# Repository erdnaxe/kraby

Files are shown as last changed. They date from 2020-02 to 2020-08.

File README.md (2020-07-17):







# Kraby

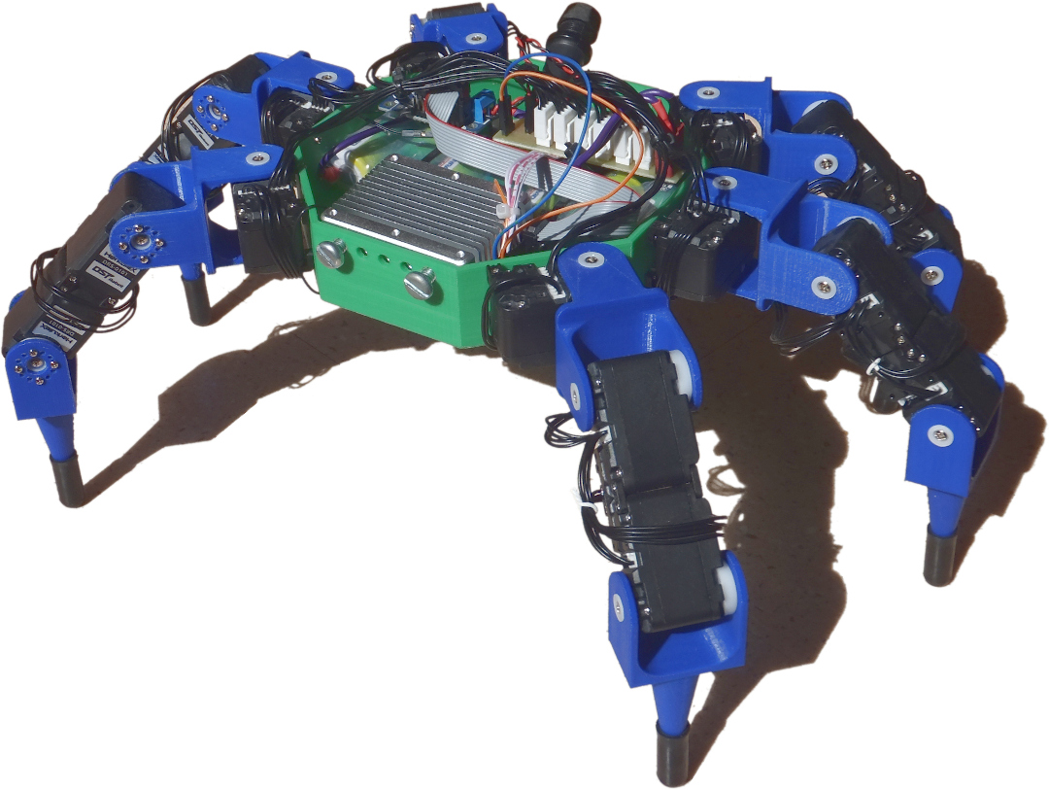
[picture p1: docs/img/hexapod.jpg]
Hexapod robot


Kraby is an hexapod robot.
It is an open source development platform for educational purpose.
It was designed for a Master 1
project at [ENS Paris-Saclay](https://ens-paris-saclay.fr/).

You may read documentation at <https://kraby.readthedocs.io/>

## Build the documentation

Install `mkdocs` then run `mkdocs serve`.

## Install OpenAI environment

```bash
pip install gym_kraby --user
python -m gym_kraby.demo
```

To test servomotors communication with the robot, you may execute `python -m gym_kraby.utils.herkulex_socket`.

## License

This project is under MIT License because we believe in
open development. Please see LICENSE file for more details.

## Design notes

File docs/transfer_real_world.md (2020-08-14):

**Table of content**:

[TOC]

* * *

# Preparing transfer to real world

The different learning experiments done last section were done with a environment time step of 50 ms,
which is the minimum period at which we can control and observe all servomotors.

As explained in [observation vector comparisons](training_one_leg.md#observation-vector-comparison),
**all the simulation observation is observable in the real world.**
No need to implement the direct mechanics to compute the position of the fingertip.

Each environment got it "real world" equivalent, that will not use PyBullet and will **not be able to compute a reward**.

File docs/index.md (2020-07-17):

# Kraby

Open-source hexapod robot.

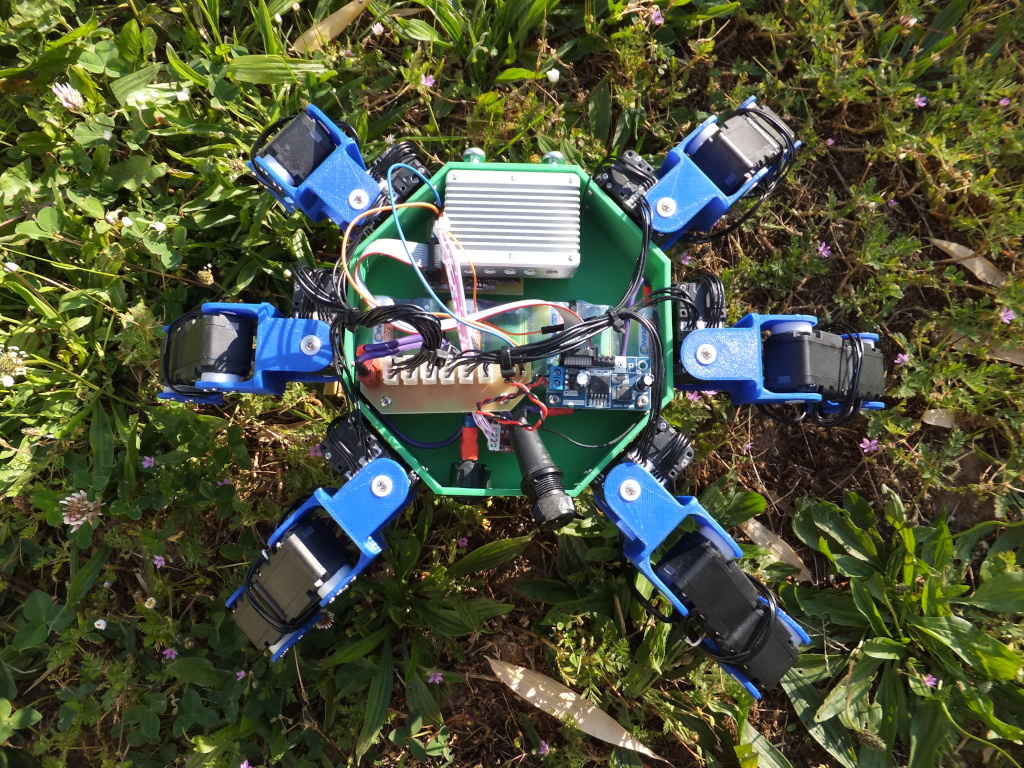
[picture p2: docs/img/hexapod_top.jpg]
Hexapod robot top view


* * *

## Overview

Kraby is an **open-source**, **3d-printable** hexapod robot that is geared towards
building a solid development platform for research and educational purpose.

The robot was designed during a Master 1
project at [ENS Paris-Saclay](https://ens-paris-saclay.fr/), France.

### Easy to remix

The robot was designed using [Blender](https://www.blender.org/),
a free and open-source 3D computer graphics editing software.
Download and remix [Kraby Blender sources](https://github.com/erdnaxe/kraby/tree/master/3d_parts/Blender).

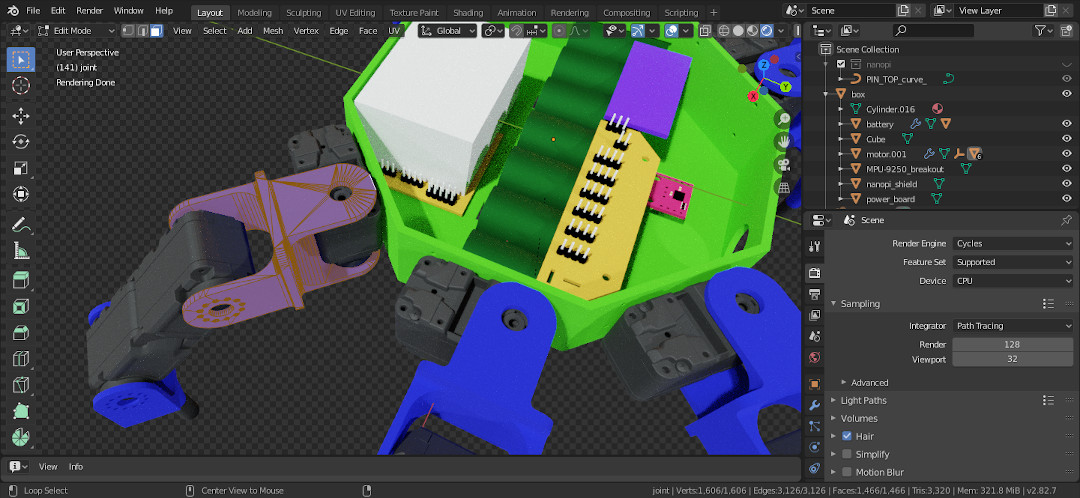
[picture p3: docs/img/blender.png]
Blender in mesh edit mode


### Smart servo-motors

Kraby uses 18 **Herkulex DRS-0101** servomotors from Dongbu to stay cost
effective while offering reasonable performances.
These includes a DC motor, a gear reducer, a control circuitry and
serial communications capability.
These servomotors are able to measure motor torque and speed, and are easy to
use with a serial port.

Even though the embedded computer has two free serial ports, getting all sensors values of 18 servomotors take an average of 40 ms, see [more details there](use_motors.md#how-slow-is-it).
This means Kraby may be too slow to do proper torque control, that is why we try to use them in position control.

These servomotors are similar to the more popular **Dynamixel AX-12**.

### Simulation environment included

[OpenAI Gym](https://gym.openai.com/) environments are available and packaged as [gym-kraby](https://pypi.org/project/gym-kraby/) on PyPi.
It uses [BulletPhysics](https://github.com/bulletphysics/bullet3) simulator
with [an URDF description](https://github.com/erdnaxe/kraby/blob/master/gym_kraby/data/hexapod.urdf) of the robot,
see [more details there](gym_environments.md).

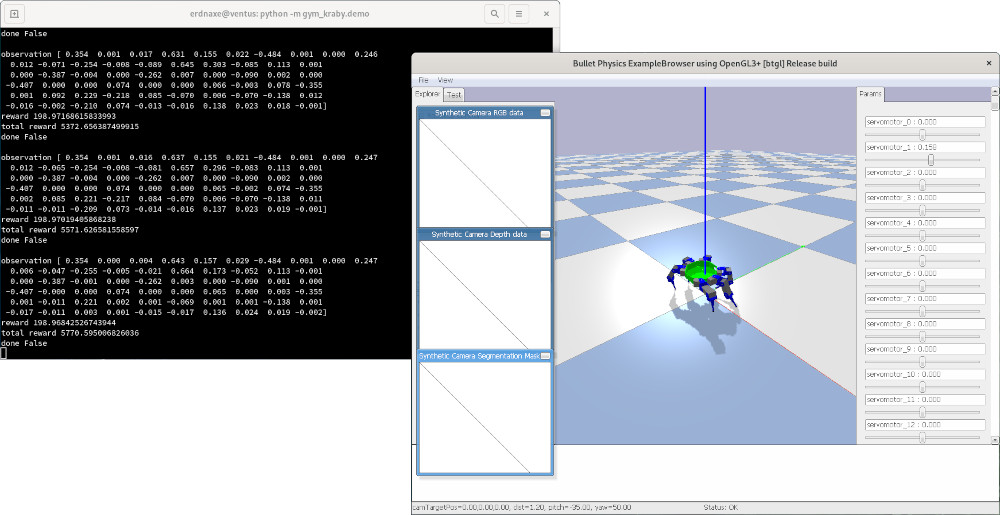
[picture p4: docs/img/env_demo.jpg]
OpenAI Gym environment


* * *

## Build instructions

To build a fully featured robot you will need to
[build the structure](build_the_structure)
then [build the electronics](build_the_electronics).

* * *

## Getting help

To get help with Kraby,
please join [#kraby:auro.re](https://matrix.to/#/#kraby:auro.re) Matrix room or
use [GitHub issues](https://github.com/erdnaxe/kraby/issues).

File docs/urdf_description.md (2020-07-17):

**Table of content**:

[TOC]

* * *

# URDF description

The **Unified Robot Description Format** (URDF) is an XML format
for representing a robot model. It has been developed
by the Robotic Operating System project (ROS).

Kraby URDF description is available at
<https://github.com/erdnaxe/kraby/blob/master/gym_kraby/data/hexapod.urdf>.

!!! Note "Do not use SDF"

    This project started with a SDFormat description of the robot in Gazebo.
    Despite PyBullet being able to load SDF files, the support is not as good as URDF files
    and some simulation parameters were impossible to input.

## Editing and building the URDF with Jinja templating

To simplify URDF editing and to avoid input errors,
the project uses Jinja2[^xacro] templates to generate the URDF.
You may edit files under
[gym_kraby/data/src/](https://github.com/erdnaxe/kraby/tree/master/gym_kraby/data/src)
then execute
[gym_kraby/data/generate_urdf.py](https://github.com/erdnaxe/kraby/tree/master/gym_kraby/data).

## Computing 3d-printed part inertia

[Meshlab](http://www.meshlab.net/) is able to compute a inertia tensor from
a STL file with the "_Compute Geometric Measures_" filter.
Nevertheless the STL is in millimeter and Meshlab implies a density of 1.
The following Python script is able to take MeshLab output and print the
corresponding inertia URDF tag.

```Python
mass = float(input("Object Mass is : "))
volume = float(input("Mesh Volume is : "))
print("Inertia Tensor is :")
j = [list(map(float, input("  ").strip().split(" "))) for _ in range(3)]

for i in range(3):
    for k in range(3):
        # Change density and convert millimeter to meter
        j[i][k] *= mass/volume*0.000001

print(f"""\n<inertia ixx="{j[0][0]:.16f}" ixy="{j[0][1]:.16f}" ixz="{j[0][2]:.16f}" iyy="{j[1][1]:.16f}" iyz="{j[1][2]:.16f}" izz="{j[2][2]:.16f}" />""")
```

For example, this is the input and output to computer a foot inertia.

```bash
% python3 compute_inertia.py
Object Mass is : 0.0105
Mesh Volume is : 15253.618164
Inertia Tensor is :
  8171479.500000 -1091.582153 858.932007
  -1091.582153 6636559.000000 29447.435547
  858.932007 29447.435547 2481984.750000    

<inertia ixx="0.0000056249300217" ixy="-0.0000000007514029"
          ixz="0.0000000005912555" iyy="0.0000045683501941"
          iyz="0.0000000202704742" izz="0.0000017085021793" />
```

For more information, see
<http://gazebosim.org/tutorials?tut=inertia&cat=build_robot>.

[^xacro]: [Xacro](http://wiki.ros.org/xacro) could also be an option, but it requires to install the ROS toolchain.

# PyBullet integration

Now that our robot is fully described in URDF, we may load it in BulletPhysics using PyBullet Python bindings.

```Python
import pybullet as p

p.connect(p.GUI)  # Open new physic server with GUI
p.setGravity(0, 0, -9.81)  # No, we are still on earth
p.setAdditionalSearchPath(getDataPath())  # Add pybullet_data
p.loadURDF("plane.urdf")  # Load a ground
p.loadURDF("hexapod.urdf")  # Load the full robot
```

You may then use `p.setJointMotorControlArray` to control motors.

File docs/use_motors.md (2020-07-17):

**Table of content**:

[TOC]

* * *

# Send and receive data from servomotors

The NanoPi NEO4 has five 3.3V UART that can go up to 1.5 Mbauds/s.
Two of these UART are used by the gigabit Ethernet controler
and one is used by the Bluetooth[^nanopi_wiki].

The [printed circuit boards](build_the_electronics.md) connect all
Herkulex DRS-0101 on NanoPi serial port `/dev/ttyS4` (UART4, 40-pin, GPIO1).
The debug UART (UART2, 8-pin, GPIO3) is unused.

## Initial set-up

To make everything go smoothly, you need to set each servomotors identifier
and make sure they are communicating at 500 000 bauds/s.
This can be done manually by connecting one servomotor at a time.
You may want to use a software like
[Herkulex Manager](http://hovis.co.kr/guide/herkulex_manager_eng.html)
to ease this process.

This indexing is the same in the URDF
and offers an easier way
to transfer a simulated control agent to the real robot.

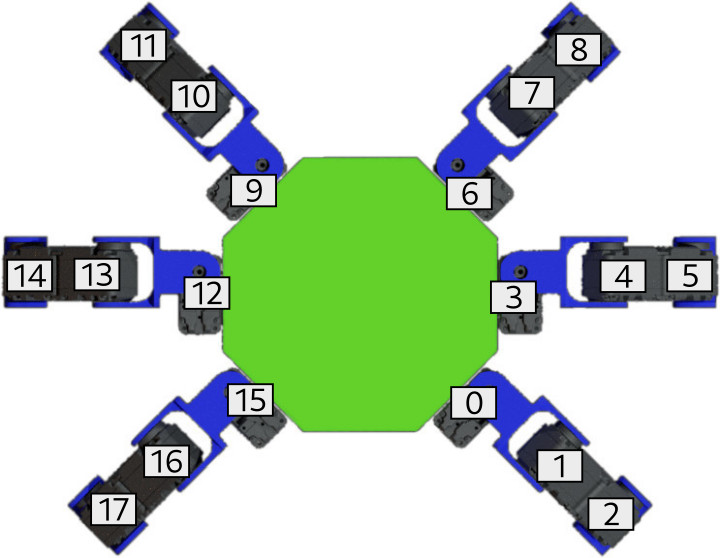
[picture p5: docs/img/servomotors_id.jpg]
servomotors id


!!! warning "Max baud-rate"

    Herkulex DRS-0101 are able to communicate in series as fast as 0.667 Mbauds/s.
    Nevertheless **RK3399 boards are unable to communicate at that baud-rate
    as their base baud-rate is 1.5 Mbaud/s[^rk3399dtsi]**.
    So 0.5 Mbaud/s is a good compromise (divided by 3 rather than 2.25).

## Server-side

### With ser2net

To ease development, `ser2net` can be used to publish
this serial port to a TCP socket.
Then, this TCP socket can be used one the same network, on a computer connected to the robot or locally.

```bash
sudo apt install ser2net
sudo systemctl enable ser2net
```

Then edit `/etc/ser2net.conf` and replace the last lines with

```ini
2000:raw:600:/dev/ttyS4:500000 8DATABITS NONE 1STOPBIT
```

This will publish `/dev/ttyS4` with a baud-rate of 500 000 baud/s,
and some common serial configuration to `0.0.0.0:2000`.

Now, you may restart the service with `sudo systemctl restart ser2net`.

!!! note

    If you improperly disconnect the socket too many times,
    then you may need to restart `ser2net` service to clean up dead sockets.

### With socat

It is possible to achieve the same result with a `socat` relay.

```bash
socat tcp-listen:2000,reuseaddr,fork file:/dev/ttyS4,raw,nonblock,waitlock=/tmp/s0.lock,echo=0,b500000
```

`tcp-listen:2000` makes socat listen on TCP 2000.
The serial TTY is open as `raw` to pass input and output unprocessed,
`nonblock` to open in nonblocking mode,
`echo=0` to disable local echo,
`b500000` to set the baud-rate.

You may also consider using UDP to achieve faster commands,

```bash
socat udp-recvfrom:2000,fork file:/dev/ttyS4,raw,nonblock,echo=0,b500000
```

You may have to write a Systemd service unit to establish these relays at boot,
edit `/etc/systemd/system/socat-tcp.service`:

```ini
[Unit]
Description=Socat TCP to ttyS4 relay
After=network-online.target

[Service]
Type=simple
ExecStart=/usr/bin/socat tcp-listen:2000,reuseaddr,fork file:/dev/ttyS4,raw,nonblock,waitlock=/tmp/s0.lock,echo=0,b500000
Restart=on-failure

[Install]
WantedBy=multi-user.target
```

## Client-side

A client implementation is available at
<https://github.com/erdnaxe/kraby/blob/master/gym_kraby/utils/herkulex_socket.py>.

This client is able to control the robot and get positions,
velocities and speeds from all servomotors.

You can send a demo choreography to `10.42.0.1:2000` with:

```bash
python -m gym_kraby.utils.herkulex_socket
```

The robot will reset to its neutral position,
then will receive position commands each 50 ms
and will finally reset to its neutral position.

<video style="max-width:100%;height:auto" preload="metadata" controls="">
<source src="https://perso.crans.org/erdnaxe/videos/projet_hexapod/herkulex_demo.mp4" type="video/mp4">
</video><br/>

### How slow is it?

The biggest bottleneck in this implementation is the data collecting.
All servomotors need to be manually pulled one at a time to get all positions,
velocities and torques.
This takes approximatively:

-   between 100 and 140 ms at 115 200 bauds/s with a TCP connection over WiFi
-   between 60 and 100 ms at 500 000 bauds/s with a TCP connection over WiFi
-   between 35 and 50 ms at 500 000 bauds/s with a local TCP connection

For the command it is much faster as it can be done using only one
`S_JOG` packet[^herkulex_manual].

[^nanopi_wiki]: "[NanoPi NEO4.](http://wiki.friendlyarm.com/wiki/index.php/NanoPi_NEO4)" FriendlyARM Wiki. October 2019.

[^herkulex_manual]: "[Herkulex DRS-0101/DRS-0201 User Manual.](https://www.robotshop.com/media/files/PDF/manual-drs-0101.pdf)" Version 1.00, March 2011.

[^rk3399dtsi]: "[RK3368 device-tree](https://github.com/torvalds/linux/blob/master/arch/arm64/boot/dts/rockchip/rk3368.dtsi#L388-L398)", lines 388-398. Linux Kernel source code. April 2020.

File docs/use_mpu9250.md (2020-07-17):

**Table of content**:

[TOC]

* * *

# Fetch raw data from MPU9250 sensors

Download, install and enable `iiod` server on NanoPi,

```bash
sudo apt install iiod
sudo systemctl enable iiod
```

Now any device on the network can interact with the inertial motion unit,
install `python3-libiio` then use the following code to get raw data,

```python
import iio

class IMUConnection:
    channels = ["accel_x", "accel_y", "accel_z",
                "anglvel_x", "anglvel_y", "anglvel_z"]

    def __init__(self, ip: str, device_name: str):
        self.ip = ip
        self.device_name = device_name

    def __enter__(self):
        """
        Connect to NanoPi and enable inertial motion unit device
        """
        context = iio.NetworkContext(self.ip)
        self.device = context.find_device(self.device_name)
        for c in self.channels:
            self.device.find_channel(c).enabled = True
        self.buffer = iio.Buffer(self.device, 1)
        return self

    def __exit__(self, *exc_info):
        """
        Disable channels on exit
        """
        for c in self.channels:
            self.device.find_channel(c).enabled = True

    def get_raw_acc_gyr(self):
        """
        Return raw output from accelerometer and gyrometer
        """
        self.buffer.refill()
        h = self.buffer.read()
        acc_raw = [int.from_bytes(h[i:i+2], byteorder='big',
                                  signed=True) for i in range(0, 6, 2)]
        gyr_raw = [int.from_bytes(h[i:i+2], byteorder='big',
                                  signed=True) for i in range(6, 12, 2)]
        return acc_raw, gyr_raw

with IMUConnection("10.42.0.1", "mpu6050") as imu:
    for i in range(100):
        acc_raw, gyr_raw = imu.get_raw_acc_gyr()
        print("Acc:", acc_raw, "Gyro:", gyr_raw)
```

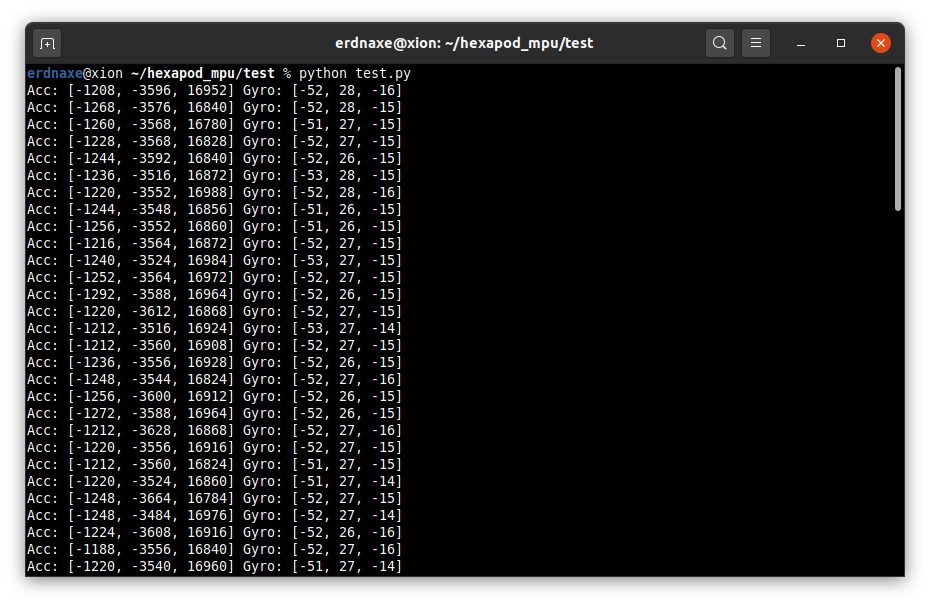
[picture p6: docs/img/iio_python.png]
IIO access in Python


!!! Note

    You may install the documentation with the `libiio0-doc` package
    and explore it by opening `/usr/share/doc/libiio0-doc/html` in a web browser.

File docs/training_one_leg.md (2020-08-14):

**Table of content**:

[TOC]

* * *

This section gives examples of hyperparameters optimization.

Let's take `ReacherBulletEnv-v0` [hyperparameters from rl-baselines-zoo](https://github.com/araffin/rl-baselines-zoo/blob/master/hyperparams/ppo2.yml#L229) as an initial base and adapt them:

```yaml
n_envs: 8 -> 32
n_timesteps: 1e6 -> 250e3
policy: 'MlpPolicy'
n_steps: 2048 -> 128  # one episode ends at 32 steps, simulate 4 episodes per environment
nminibatches: 32 -> auto
lam: 0.95
gamma: 0.99 -> 0.90
noptepochs: 10 -> 30
ent_coef: 0.0 -> 0.01
learning_rate: 2.5e-4 -> 10e-4
cliprange: 0.2
```

# Observation vector comparison

When building the OpenAI Gym environment, many observations vectors are possible.
On the one hand removing data from observation that was required for learning will plumbed learning sample efficiency,
on the other hand adding useless observation will slow down the learning.

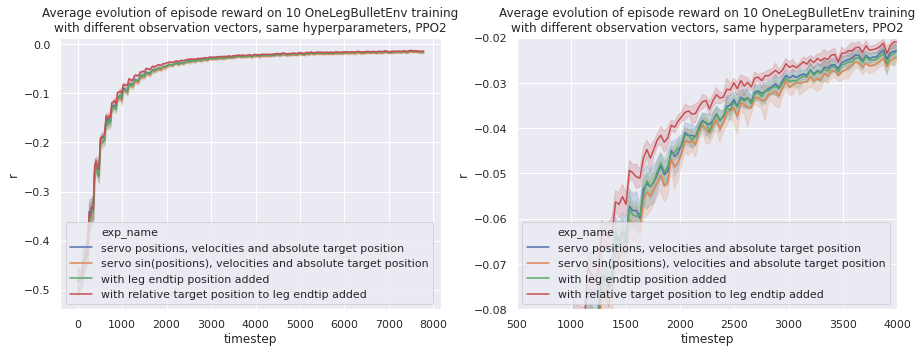
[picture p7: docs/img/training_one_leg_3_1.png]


`ReacherBulletEnv-v0` uses cosinus and sinus for their angular observation.
In our case we only need the sinus of the servomotor position as the range go from $-\\pi/2$ to $\\pi/2$.
We observe that this does not help with learning (yellow plot).

One interesting observation is that we get quite the same learning performance with and without the absolute leg endtip position.
This means that we won't have to implement the direct mechanics of the leg when transferring this environment to reality.
**The agent learns the direct mechanics of the leg.**

**Overall tweaking the observation vector did not affect performance as much as optimizing hyperparameters.**
It is much more interesting to optimize learning hyperparameters rather than finding the perfect observation.

For all future training we will keep the following observation vector :
$$
obs = \\begin{pmatrix}
\\theta_1 \\ \\omega_1 \\ \\theta_2 \\ \\omega_2 \\ \\theta_3 \\ \\omega_3 \\ target_x \\ target_y \\ target_z \\end{pmatrix}
$$
$\\theta_i$ being the angle normalized between -1 (-90°) and 1 (90°) and $\\omega_i$ the velocity normalized.

# Optimizing the number of parallel environments

Each environment instantiate a PyBullet world with one leg.
If we instantiate only one environment (`n_envs=1`), data generation will be slow and won't use all computer resources.

We observed that on a i7-8750H (6 physical cores, 12 logical cores), `n_envs=12` did not use the most out of the processor.
Increasing the number of environment even higher helps gain some speed.

One environment uses CPU and RAM resources. One rule of thumb is to increase `n_envs` until we utilized all the memory.
`n_envs=32` requires approximately 12 GiB of RAM, and that is the sweet spot I used on my 16 GiB laptop.

# Tweaking the batch size

**The batch size represents the size of one batch of data that will be used for one learning epoch.**
Because learning is done on GPU and we are using small dimensions, increasing batch size should use more GPU resources and increase learning speed.

Also because the target and initial position of each simulation epoch is random, we need a large-enough batch size to have some variance.

Because we fixed `n_envs` in last step, the batch size can only be changed by tweaking the number of simulation episodes in each environment, or the number of minibatches.

$$
batch~size = \\frac{n_{steps} \\times n_{envs}}{n\_{minibatches}}
$$

## Tweaking the number of minibatches

With `nminibatches=1` we have no "mini batches", it is a **Batch Gradient Descent**.

Increasing `nminibatches` will cut the dataset generated by the simulations. This is **Mini Batch Gradient Descent**.
You can learn more about this on [this blog post](https://towardsdatascience.com/batch-mini-batch-stochastic-gradient-descent-7a62ecba642a).

Having `nminibatches` over 1 should decrease performances in our case because we are not learning over a huge dataset.

The following training was done with `n_envs=32` and `n_steps=128`. **So without mini batches we get the maximal batch size of 4096 simulation steps.**

<details>
   <summary>
    Show the code used for these learning.
   </summary>

```python
from gym_kraby.train import train

for batch_size in [32, 64, 128, 256, 512, 1024, 2048, 4096]:
    n_envs = 32  # opti
    n_steps = 128  # 4 simulation episodes per simulation

    if n_steps * n_envs < batch_size:
        nminibatches = 1  # limit batch_size to 32*128=4096
    else:
        nminibatches = int(n_steps * n_envs / batch_size)

    print("[+] Train hyperparam_batch_size_" + str(batch_size))
    train(
        exp_name="hyperparam_batch_size_" + str(batch_size),
        env_name="gym_kraby:OneLegBulletEnv-v0",
        n_envs=n_envs,
        gamma=0.90,  # Discount factor
        n_steps=n_steps,  # batchsize = n_steps * n_envs
        ent_coef=0.01,  # Entropy coefficient for the loss calculation
        learning_rate=10e-4,
        lam=0.95,  # Factor for trade-off of bias vs variance for Generalized Advantage Estimator
        nminibatches=nminibatches,  # Number of training minibatches per update.
        noptepochs=30,  # Number of epoch when optimizing the surrogate
        cliprange=0.2,  # Clipping parameter, this clipping depends on the reward scaling
    )
```

</details><br/>

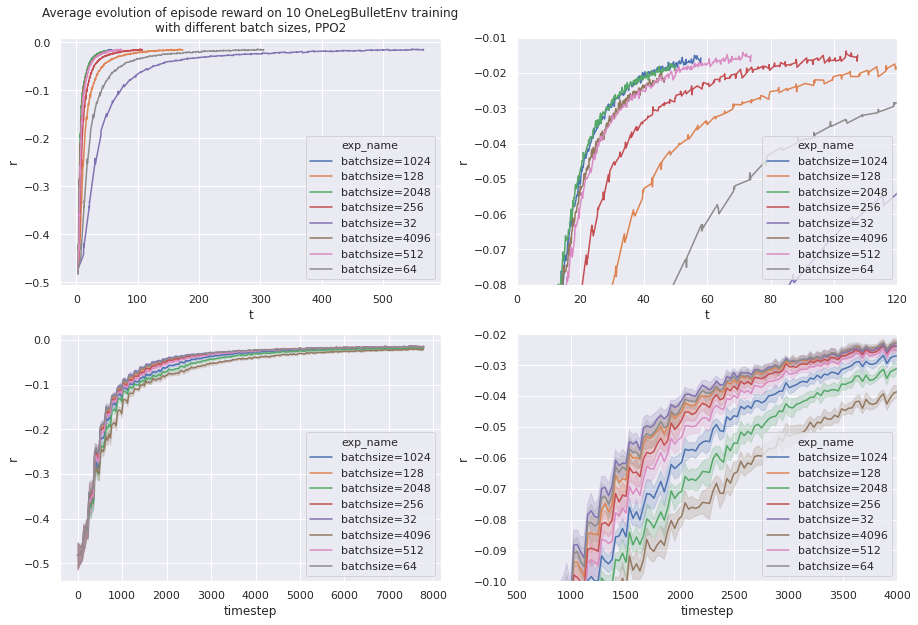
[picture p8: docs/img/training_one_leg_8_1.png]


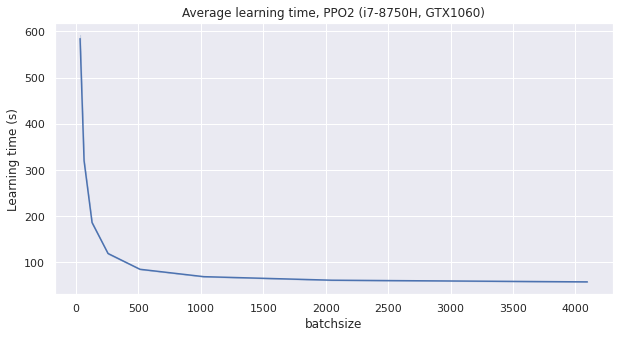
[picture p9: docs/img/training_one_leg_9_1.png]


Lowering batch size using mini batches make small improvement of learning sample efficiency, but plumb the overall real world learning speed.

The conclusion of this experience is that we can keep `nminibatch=1` i.e. not splitting the generated data into smaller batch for the learning process. The batch size will be decided by the amount of environments multiplied by the number of simulated steps in each environments.

## Tweaking the number of simulation episodes

As a simulation episode contains 32 steps, so the number of steps `n_steps` generated by one environment correspond to $32 \\times n\_{episodes}$.

This experience change the amount of simulation episodes done in each environments (32 environments in our case). More simulation episodes will use more CPU time and create a larger batch of data.

<details>
   <summary>
    Show the code used for these learning.
   </summary>

```python
from gym_kraby.train import train

for n_steps in [32, 64, 128, 256, 512, 1024, 2048]:
    n_envs = 32  # opti
    nminibatches = 1  # opti

    print("[+] Train hyperparam_n_steps_" + str(n_steps))
    train(
        exp_name="hyperparam_n_steps_" + str(n_steps),
        env_name="gym_kraby:OneLegBulletEnv-v0",
        n_envs=n_envs,
        gamma=0.90,  # Discount factor
        n_steps=n_steps,  # batchsize = n_steps * n_envs
        ent_coef=0.01,  # Entropy coefficient for the loss calculation
        learning_rate=10e-4,
        lam=0.95,  # Factor for trade-off of bias vs variance for Generalized Advantage Estimator
        nminibatches=nminibatches,  # Number of training minibatches per update.
        noptepochs=30,  # Number of epoch when optimizing the surrogate
        cliprange=0.2,  # Clipping parameter, this clipping depends on the reward scaling
    )
```

</details><br/>

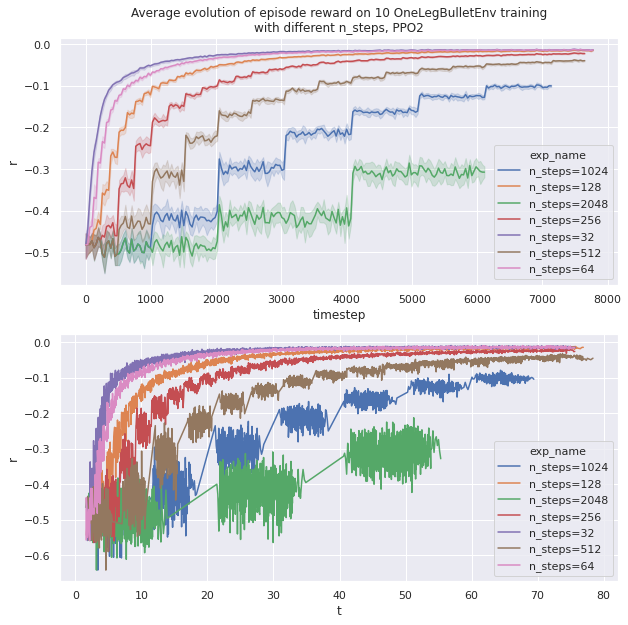
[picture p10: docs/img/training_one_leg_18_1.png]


The more `n_steps` grows, the more GPU time is needed. A too large batch size deteriorates performances. In fact one episode on 32 simulations seems plenty enough to have enough variance in the dataset.

When `n_steps` is larger, the total learning time is a bit faster as the timestep limit is 250k and it does not divide well with high power of 2. It is also a bit faster because less data transfer occurs

# Tweaking number of optimization epoch

The number of optimization epoch (`noptepochs`) represents how many times we will use our generated data to optimize the neural network and reduce the surrogate.

A higher number of optimization epoch will use more GPU and may improve sample efficiency. If too many optimization epoch are done, the learning process will be slower.

<details>
   <summary>
    Show the code used for these learning.
   </summary>

```python
from gym_kraby.train import train

for noptepochs in [1, 5, 10, 20, 30, 50]:
    n_envs = 32  # opti
    n_steps = 128  # 4 simulation episodes per simulation
    nminibatches = 1  # opti

    print("[+] Train hyperparam_noptepochs_" + str(noptepochs))
    train(
        exp_name="hyperparam_noptepochs_" + str(noptepochs),
        env_name="gym_kraby:OneLegBulletEnv-v0",
        n_envs=n_envs,
        gamma=0.90,  # Discount factor
        n_steps=n_steps,  # batchsize = n_steps * n_envs
        ent_coef=0.01,  # Entropy coefficient for the loss calculation
        learning_rate=10e-4,
        lam=0.95,  # Factor for trade-off of bias vs variance for Generalized Advantage Estimator
        nminibatches=nminibatches,  # Number of training minibatches per update.
        noptepochs=noptepochs,  # Number of epoch when optimizing the surrogate
        cliprange=0.2,  # Clipping parameter, this clipping depends on the reward scaling
    )
```

</details><br/>

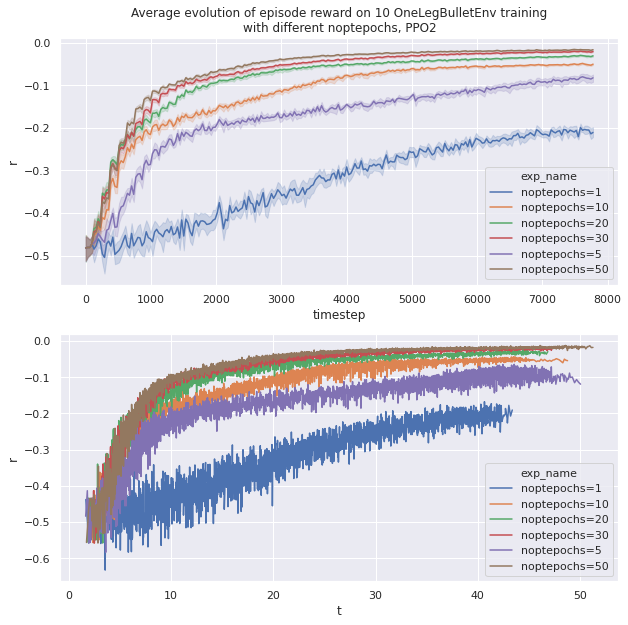
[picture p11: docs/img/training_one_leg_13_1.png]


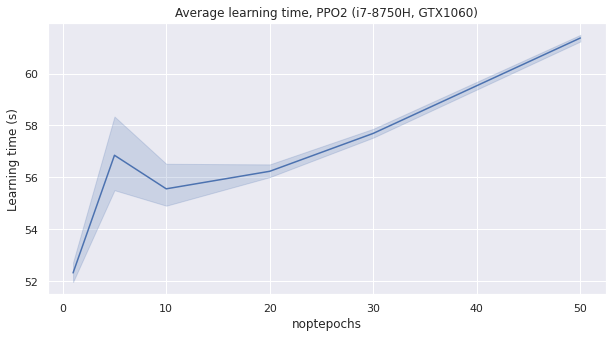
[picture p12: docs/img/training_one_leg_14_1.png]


We observe as intended that increasing `noptepochs` makes the learning more sample efficient, but slower.
A good compromise seems to be `noptepochs=30`.

# Tweaking the discount factor

**The discount factor (`gamma`, $\\gamma$) is the coefficient used when summing all step rewards to get the episode return.**

$$
return = \\sum_n \\gamma^n~reward_n
$$

$\\gamma=1$ means that the learning does not differentiate between achieving good reward early or lately in the simulation episode.
We often see a value of $\\gamma$ between 0.9 and 0.999 in literature to promote getting good rewards early.

<details>
   <summary>
    Show the code used for these learning.
   </summary>

```python
from gym_kraby.train import train

for gamma in [0.2, 0.4, 0.6, 0.8, 0.9, 0.95, 0.98, 0.9999]:
    n_envs = 32  # opti
    nminibatches = 1  # opti
    noptepochs = 30  # opti
    n_steps = 32  # opti

    print("[+] Train hyperparam_gamma_" + str(gamma))
    train(
        exp_name="hyperparam_gamma_" + str(gamma),
        env_name="gym_kraby:OneLegBulletEnv-v0",
        n_envs=n_envs,
        gamma=gamma,  # Discount factor
        n_steps=n_steps,  # batchsize = n_steps * n_envs
        ent_coef=0.01,  # Entropy coefficient for the loss calculation
        learning_rate=10e-4,
        lam=0.95,  # Factor for trade-off of bias vs variance for Generalized Advantage Estimator
        nminibatches=nminibatches,  # Number of training minibatches per update.
        noptepochs=noptepochs,  # Number of epoch when optimizing the surrogate
        cliprange=0.2,  # Clipping parameter, this clipping depends on the reward scaling
    )
```

</details><br/>

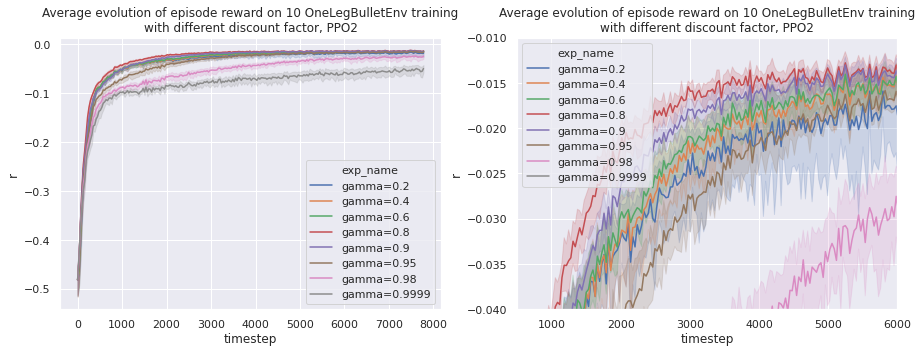
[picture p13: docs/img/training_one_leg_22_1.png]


We observe that a discount factor between 0.8 and 0.9 gives best results. If the discount is too low or too high, then the repeatability of the learning decreases.

!!! warning

    We use the distance between the target and the robot leg end as reward at every step. This leads to a negative return to maximize. Much better performances might be achievable using the derivative.

# Tweaking the clip range

The PPO algorithm avoid too large policy update by clipping it. It uses a ratio that tell the difference between new and old policy and clip this ratio.
With a clip range of $\\varepsilon=0.2$, the ratio will be clipped from $1-\\varepsilon = 0.8$ to $1+\\varepsilon = 1.2$.

<details>
   <summary>
    Show the code used for these learning.
   </summary>

```python
from gym_kraby.train import train

for cliprange in [0.1, 0.2, 0.3, 0.4]:
    n_envs = 32  # opti
    nminibatches = 1  # opti
    noptepochs = 30  # opti
    n_steps = 32  # opti
    gamma = 0.8  # opti

    print("[+] Train hyperparam_cliprange_" + str(cliprange))
    train(
        exp_name="hyperparam_cliprange_" + str(cliprange),
        env_name="gym_kraby:OneLegBulletEnv-v0",
        n_envs=n_envs,
        gamma=gamma,  # Discount factor
        n_steps=n_steps,  # batchsize = n_steps * n_envs
        ent_coef=0.01,  # Entropy coefficient for the loss calculation
        learning_rate=10e-4,
        lam=0.95,  # Factor for trade-off of bias vs variance for Generalized Advantage Estimator
        nminibatches=nminibatches,  # Number of training minibatches per update.
        noptepochs=noptepochs,  # Number of epoch when optimizing the surrogate
        cliprange=cliprange,  # Clipping parameter, this clipping depends on the reward scaling
    )
```

</details><br/>

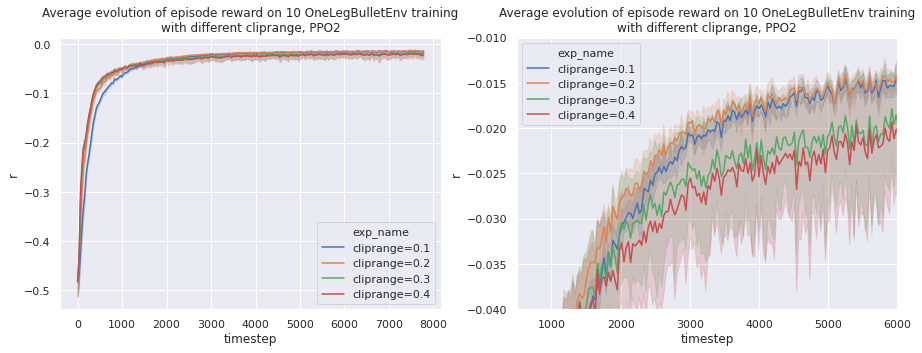
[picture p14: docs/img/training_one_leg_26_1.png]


It seams that a clip range of 0.1 clips the update too much and degrade learning performance.
On the contrary, a clip range over 0.2 makes the policy updates too far and also degrade performance and repeatability.

# Tweaking the learning rate

The learning rate is another important hyperparameter. **It represents the size of learning steps done by the Adam optimizer.**
A bigger learning rate will increase learning speed but the learning might not converge as well as with a smaller rate.

<details>
   <summary>
    Show the code used for these learning.
   </summary>

```python
from gym_kraby.train import train

for learning_rate in [1e-4, 1e-3, 1e-2, 1e-1, 1]:
    n_envs = 32  # opti
    nminibatches = 1  # opti
    noptepochs = 30  # opti
    n_steps = 32  # opti
    gamma = 0.8  # opti
    cliprange = 0.2  # opti

    print("[+] Train hyperparam_learning_rate_" + str(learning_rate))
    train(
        exp_name="hyperparam_learning_rate_" + str(learning_rate),
        env_name="gym_kraby:OneLegBulletEnv-v0",
        n_envs=n_envs,
        gamma=gamma,  # Discount factor
        n_steps=n_steps,  # batchsize = n_steps * n_envs
        ent_coef=0.01,  # Entropy coefficient for the loss calculation
        learning_rate=learning_rate,
        lam=0.95,  # Factor for trade-off of bias vs variance for Generalized Advantage Estimator
        nminibatches=nminibatches,  # Number of training minibatches per update.
        noptepochs=noptepochs,  # Number of epoch when optimizing the surrogate
        cliprange=cliprange,  # Clipping parameter, this clipping depends on the reward scaling
    )
```

</details><br/>

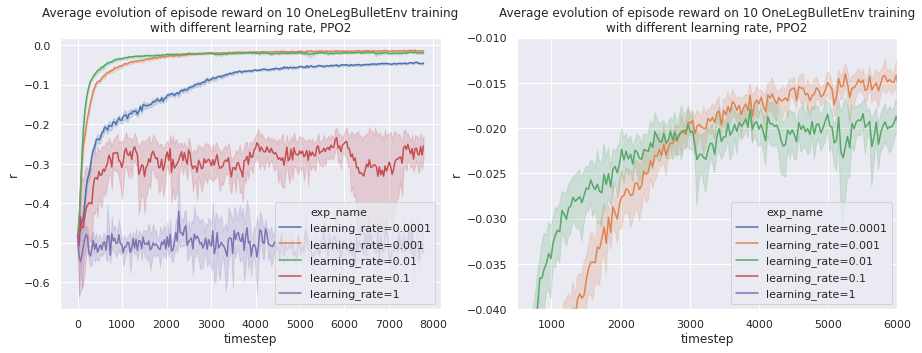
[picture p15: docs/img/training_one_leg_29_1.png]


A learning rate of 0.01 gives the best sample efficiency. A smaller rate makes the learning converge closer to an optimal policy. One way to address this would be to lower the learning rate during the training.

# Tweaking the GAE smoothing factor

**The `lam` hyperparameter represents the smoothing factor $\\lambda$ in the Generalized Advantage Estimation.**
The Generalized Advantage Estimation is a method to estimate the advantage used by PPO.

<details>
   <summary>
    Show the code used for these learning.
   </summary>

```python
from gym_kraby.train import train

for lam in [0.8, 0.9, 0.92, 0.95, 0.98, 0.99, 1.0]:
    n_envs = 32  # opti
    nminibatches = 1  # opti
    noptepochs = 30  # opti
    n_steps = 32  # opti
    gamma = 0.8  # opti
    cliprange = 0.2  # opti
    learning_rate = 0.01  # opti

    print("[+] Train hyperparam_lam_" + str(lam))
    train(
        exp_name="hyperparam_lam_" + str(lam),
        env_name="gym_kraby:OneLegBulletEnv-v0",
        n_envs=n_envs,
        gamma=gamma,  # Discount factor
        n_steps=n_steps,  # batchsize = n_steps * n_envs
        ent_coef=0.01,  # Entropy coefficient for the loss calculation
        learning_rate=learning_rate,
        lam=lam,  # Factor for trade-off of bias vs variance for Generalized Advantage Estimator
        nminibatches=nminibatches,  # Number of training minibatches per update.
        noptepochs=noptepochs,  # Number of epoch when optimizing the surrogate
        cliprange=cliprange,  # Clipping parameter, this clipping depends on the reward scaling
    )
```

</details><br/>

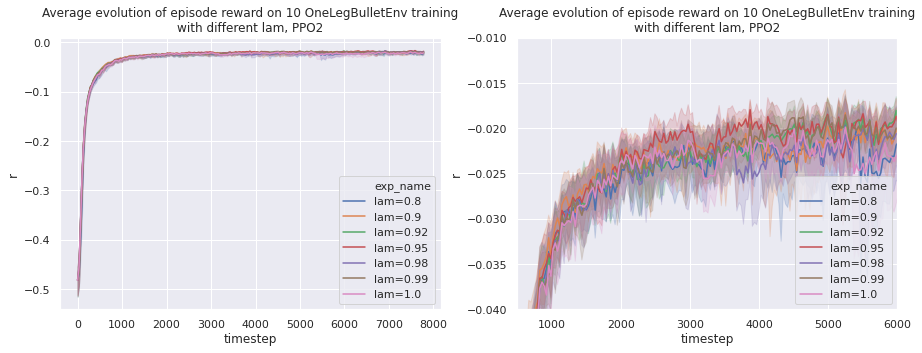
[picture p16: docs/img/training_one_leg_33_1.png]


On our environment, this factor does not influence much. Even going far from common values seen in literature (0.9 to 1.0) yields similar performances.

# Tweaking the entropy coefficient

`ent_coef` is the entropy coefficient for the loss calculation. 

When optimizing the neural network, one summed term of the loss function represents the entropy of the exploration.
Raising this coefficient of ponderation will make the learning explore a bit more.

<details>
   <summary>
    Show the code used for these learning.
   </summary>

```python
from gym_kraby.train import train

for ent_coef in [0.00000001, 0.000001, 0.0001, 0.01, 0.1]:
    n_envs = 32  # opti
    nminibatches = 1  # opti
    noptepochs = 30  # opti
    n_steps = 32  # opti
    gamma = 0.8  # opti
    cliprange = 0.2  # opti
    learning_rate = 0.01  # opti
    lam = 0.95  # opti

    print("[+] Train hyperparam_ent_coef_" + str(ent_coef))
    train(
        exp_name="hyperparam_ent_coef_" + str(ent_coef),
        env_name="gym_kraby:OneLegBulletEnv-v0",
        n_envs=n_envs,
        gamma=gamma,  # Discount factor
        n_steps=n_steps,  # batchsize = n_steps * n_envs
        ent_coef=ent_coef,  # Entropy coefficient for the loss calculation
        learning_rate=learning_rate,
        lam=lam,  # Factor for trade-off of bias vs variance for Generalized Advantage Estimator
        nminibatches=nminibatches,  # Number of training minibatches per update.
        noptepochs=noptepochs,  # Number of epoch when optimizing the surrogate
        cliprange=cliprange,  # Clipping parameter, this clipping depends on the reward scaling
    )
```

</details><br/>

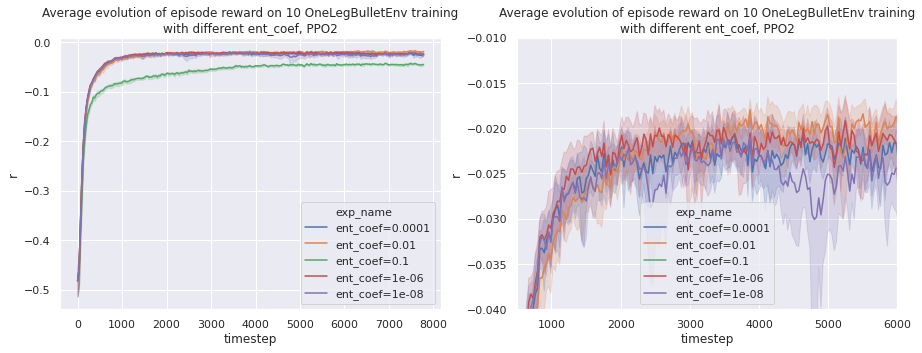
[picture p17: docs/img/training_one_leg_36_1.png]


We observe that a `ent_coef=0.01` gives good results. Going higher makes the learning slower as we are exploring too much.

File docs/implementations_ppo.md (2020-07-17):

**Table of content**:

[TOC]

* * *

# Choosing a learning algorithm

This project choose to use **Proximal Policy Optimization** which is an **on-policy**, policy gradient method.
Other popular algorithm are:

-   **Deep Q-learning** (DQN) which works well on environments with discrete action spaces but performs less well on continuous control benchmarks. "Q-learning quickly become infeasible when naive discretization of the action space is performed, due to the curse  of  dimensionality", [[Duan et al., 2016](references.md#DuanCHSA16)].
-   **"Vanilla" Policy Gradient** methods which have poor data efficiency and robustness.
-   **Trust Region / natural Policy gradient** methods (such as TRPO) which has a similar data efficiency and performance compared to PPO, while being more complicated [[Schulman et al., 2017](references.md#schulman2017ppo)].

## On-policy vs Off-policy

An **on-policy** algorithm does not use old data.
In our case it means that one batch of simulation episodes will one be used to train the next policy,
and sample won't be stored in memory to be reused later.

This implies that on-policy algorithms are less sample efficient compared to off-policy.
Nonetheless it increases learning stability.

> These algorithms directly optimize [...] policy performance and it works out mathematically that you need on-policy data to calculate the updates. So, this family of algorithms trades off sample efficiency in favor of stability—but you can see the progression of techniques (from VPG to TRPO to PPO) working to make up the deficit on sample efficiency. <br/>
> \-- [Algorithms, OpenAI SpinningUp](https://spinningup.openai.com/en/latest/user/algorithms.html#the-on-policy-algorithms)

## Policy Gradient Methods

Policy gradient methods directly optimize the episode return.

Let's define some common notations in reinforcement learning:

-   $\theta$ contains parameters to optimize,
-   $a_t$ is the action taken and $s_t$ the observation at step $t$.
-   $\pi_θ$ is a stochastic policy,
-   $\hat A_t$ is an estimator of the advantage function at time step $t$, see [[Schulman et al., 2015](references.md#schulman2015high)].

Policy Gradient Methods estimate the gradient estimator $g$ at the step $t$ with an empirical average over a **batch of sample**,
for Actor-Critic algorithms (see A2C and PPO) the form is
$$
\hat g = \hat{\mathbb E}_t \left[ \nabla_θ \log \pi_θ (a_t|s_t) \hat A_t \right]
$$

Then this gradient estimate is used in a stochastic gradient ascent algorithm. The one our implementation uses is **Adaptive Moment Estimation** [[Kingma and Ba, 2014](references.md#kingma2014method)].

When training we will alternate between running simulation environments to generate a batch of sample (CPU/RAM bottlenecked)
and optimization (GPU).

# Proximal Policy Optimization

Proximal Policy Optimization is a policy gradient method for reinforcement
learning developed by OpenAI [[Schulman et al., 2017](references.md#schulman2017ppo)].
The following video explains clearly how Proximal Policy Optimization works.

<iframe width="560" height="315" src="https://www.youtube-nocookie.com/embed/5P7I-xPq8u8" frameborder="0" allow="accelerometer; autoplay; encrypted-media; gyroscope; picture-in-picture" allowfullscreen></iframe>

Original paper : <https://arxiv.org/abs/1707.06347>.

## Using different implementations of PPO

The following implementations were tested:

-   [pytorch-a2c-ppo-acktr-gail](https://github.com/ikostrikov/pytorch-a2c-ppo-acktr-gail) (PyTorch),
-   [StableBaselines](https://github.com/hill-a/stable-baselines) (Tensorflow 1),
-   [StableBaselines3](https://github.com/DLR-RM/stable-baselines3) (PyTorch),
-   [OpenAI SpinningUp](https://github.com/openai/spinningup) (PyTorch and Tensorflow 1).

OpenAI developed internally a new training system called [OpenAI Rapid](https://openai.com/blog/openai-five/#rapid)
implementing PPO at large scale. It can train a policy on large cloud
platform (such as Kubernetes) using CPU workers for rollout and eval and GPU
workers for optimization[^OpenAI_Rapid].
Other companies are developing alternatives such as
[Facebook ReAgent](https://github.com/facebookresearch/ReAgent)
or [Intel Coach](https://github.com/NervanaSystems/coach).

[Garage](https://github.com/rlworkgroup/garage) also implements PPO for
Tensorflow and PyTorch
but Garage documentation does not introduce as many concepts as StableBaselines
and is more intended for experimented users. 

[TensorForce](https://github.com/tensorforce/tensorforce) implements PPO
for Tensorflow 2 which gives access to the new profiler and tools compared to the other toolkits.
It also provides a hyperparameter tuner. Like Garage, it is also geared towards
more experimented users.

[RLlib](https://docs.ray.io/en/latest/rllib-algorithms.html#ppo) implements PPO
in a scalable way with PyTorch. This implementation looks promising but has not been tested.

### Using pytorch-a2c-ppo-acktr-gail PPO (PyTorch)

[pytorch-a2c-ppo-acktr-gail](https://github.com/ikostrikov/pytorch-a2c-ppo-acktr-gail)
is a PPO implementation with PyTorch.
It is simple to use but lacks many features compared to other toolkits.

You need to install PyTorch and NVIDIA Cuda for GPU acceleration.
On ArchLinux you may just need to install `python-pytorch-opt-cuda`
witch is a compiled version of PyTorch
for post Hashell Intel CPU and NVIDIA Cuda.

Then clone the source code and start training,

```bash
git clone https://github.com/ikostrikov/pytorch-a2c-ppo-acktr-gail
cd pytorch-a2c-ppo-acktr-gail
python main.py --env-name gym_kraby:OneLegBulletEnv-v0 --algo ppo --use-gae \
               --log-interval 1 --num-steps 2048 --num-processes 1 --lr 3e-4 \
               --entropy-coef 0 --value-loss-coef 0.5 --ppo-epoch 10 \
               --num-mini-batch 32 --gamma 0.99 --gae-lambda 0.95 \
               --num-env-steps 1000000 --use-linear-lr-decay --no-cuda \
               --seed 0 --use-proper-time-limits
```

Then follow instructions of the README.

!!! Note "Running simultaneous training"

    [generate_tmux_yaml.py](https://github.com/ikostrikov/pytorch-a2c-ppo-acktr-gail/blob/master/generate_tmux_yaml.py)
    generates a tmuxp Yaml configuration file to launch simultaneous experiments.
    You can run the experiments with
    `tmuxp load run_all.yaml`.

### Using StableBaselines PPO (Tensorflow 1)

[StableBaselines](https://github.com/hill-a/stable-baselines) is a fork
of OpenAI Baselines that make it more easier to use for beginners
and cleans up the code base.
[StableBaselines documentation](https://stable-baselines.readthedocs.io/en/master/)
introduces many key concepts and is quite clear about PPO parameters.

As StableBaselines current stable version supports only Tensorflow 1,
you may use Docker to isolate the requirements.
More detailed instructions are available at
[Tensorflow documentation](https://www.tensorflow.org/install/docker).
Install `docker` and `nvidia-container-toolkit`,
restart `docker` daemon then start a Jupyter Notebook environment
as your user and with GPU support by running in repository folder:

```bash
docker build -f Dockerfile.stablebaselines -t kraby-stablebaselines .
docker run -it -u $(id -u):$(id -g) --gpus all --rm \
    --env="DISPLAY"  --volume="/tmp/.X11-unix:/tmp/.X11-unix:rw" \
    -v $(pwd):/tf/kraby -p 8888:8888 kraby-stablebaselines
```

Some notebooks are available in `kraby/notebooks/stablebaselines/`.

!!! Note

    `-u $(id -u):$(id -g) --env="DISPLAY"  --volume="/tmp/.X11-unix:/tmp/.X11-unix:rw"` is required to use X11 windows in Docker container and launch PyBullet debugging GUI. It forwards the host X11 server.

### Using OpenAI Spinning Up PPO (PyTorch)

[OpenAI Spinning Up](https://spinningup.openai.com/en/latest/) is a more recent
implementation than OpenAI Baselines.
It is geared toward giving a well-documented code repository of short
implementations of key algorithms.

For an easier setup you may use Docker to isolate the requirements.
Install `docker` and `nvidia-container-toolkit`,
restart `docker` daemon then start a Jupyter Notebook environment
as your user and with GPU support by running in repository folder:

```bash
docker build -f Dockerfile.spinningup -t kraby-spinningup .
docker run -it -u $(id -u):$(id -g) --gpus all --ipc=host --rm \
    -v $(pwd):/workdir -v $(pwd)/spinningup_data:/opt/spinningup/data \
    -p 8888:8888 kraby-spinningup
```

Some notebooks are available in `kraby/notebooks/spinningup/`.

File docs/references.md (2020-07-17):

# References

<!-- Generate with
bibtex2html -dl -nobibsource -noheader -nofooter -noabstract -nokeywords -d -nodoc -s apalike docs/bibliography.bib
-->

<dl>

<dt>
[<a name="sutton1998">Sutton and Barto, 1998</a>]
</dt>
<dd>
Sutton, R.&nbsp;S. and Barto, A.&nbsp;G. (1998).
 <em>Reinforcement Learning: An Introduction</em>.
 The MIT Press.

</dd>

<dt>
[<a name="madgwick2010efficient">Madgwick et&nbsp;al., 2010</a>]
</dt>
<dd>
Madgwick, S., Vaidyanathan, R., and Harrison, A. (2010).
 An efficient orientation filter for inertial measurement units (imus)
  and magnetic angular rate and gravity (marg) sensor arrays.
 Technical report, Department of Mechanical Engineering.
[&nbsp;<a href="http://www.scribd.com/doc/29754518/A-Efficient-Orientation-Filter-for-IMUs-and-MARG-Sensor-Arrays">http</a>&nbsp;]

</dd>

<dt>
[<a name="kingma2014method">Kingma and Ba, 2014</a>]
</dt>
<dd>
Kingma, D.&nbsp;P. and Ba, J. (2014).
 Adam: A method for stochastic optimization.
[&nbsp;<a href="https://arxiv.org/abs/1412.6980">http</a>&nbsp;]

</dd>

<dt>
[<a name="schulman2015high">Schulman et&nbsp;al., 2015</a>]
</dt>
<dd>
Schulman, J., Moritz, P., Levine, S., Jordan, M., and Abbeel, P. (2015).
 High-dimensional continuous control using generalized advantage
  estimation.
[&nbsp;<a href="https://arxiv.org/abs/1506.02438">http</a>&nbsp;]

</dd>

<dt>
[<a name="coumans2020">Coumans and Bai, 2016</a>]
</dt>
<dd>
Coumans, E. and Bai, Y. (2016).
 Pybullet, a python module for physics simulation for games, robotics
  and machine learning.
[&nbsp;<a href="http://pybullet.org">http</a>&nbsp;]

</dd>

<dt>
[<a name="brockman2016openai">Brockman et&nbsp;al., 2016</a>]
</dt>
<dd>
Brockman, G., Cheung, V., Pettersson, L., Schneider, J., Schulman, J., Tang,
  J., and Zaremba, W. (2016).
 Openai gym.
[&nbsp;<a href="https://arxiv.org/abs/1606.01540">http</a>&nbsp;]

</dd>

<dt>
[<a name="DuanCHSA16">Duan et&nbsp;al., 2016</a>]
</dt>
<dd>
Duan, Y., Chen, X., Houthooft, R., Schulman, J., and Abbeel, P. (2016).
 Benchmarking deep reinforcement learning for continuous control.
 <em>CoRR</em>.
[&nbsp;<a href="https://arxiv.org/abs/1604.06778">http</a>&nbsp;]

</dd>

<dt>
[<a name="henderson2017">Henderson et&nbsp;al., 2017</a>]
</dt>
<dd>
Henderson, P., Islam, R., Bachman, P., Pineau, J., Precup, D., and Meger, D.
  (2017).
 Deep reinforcement learning that matters.
[&nbsp;<a href="https://arxiv.org/abs/1709.06560">http</a>&nbsp;]

</dd>

<dt>
[<a name="schulman2017ppo">Schulman et&nbsp;al., 2017</a>]
</dt>
<dd>
Schulman, J., Wolski, F., Dhariwal, P., Radford, A., and Klimov, O. (2017).
 Proximal policy optimization algorithms.
 <em>CoRR</em>.
[&nbsp;<a href="https://arxiv.org/abs/1707.06347">http</a>&nbsp;]

</dd>

<dt>
[<a name="SpinningUp2018">Achiam, 2018</a>]
</dt>
<dd>
Achiam, J. (2018).
 Spinning up in deep reinforcement learning.
[&nbsp;<a href="https://spinningup.openai.com">http</a>&nbsp;]

</dd>

<dt>
[<a name="tan2018sim">Tan et&nbsp;al., 2018</a>]
</dt>
<dd>
Tan, J., Zhang, T., Coumans, E., Iscen, A., Bai, Y., Hafner, D., Bohez, S., and
  Vanhoucke, V. (2018).
 Sim-to-real: Learning agile locomotion for quadruped robots.
[&nbsp;<a href="https://arxiv.org/abs/1804.10332">http</a>&nbsp;]

</dd>

<dt>
[<a name="stable-baselines">Hill et&nbsp;al., 2018</a>]
</dt>
<dd>
Hill, A., Raffin, A., Ernestus, M., Gleave, A., Kanervisto, A., Traore, R.,
  Dhariwal, P., Hesse, C., Klimov, O., Nichol, A., Plappert, M., Radford, A.,
  Schulman, J., Sidor, S., and Wu, Y. (2018).
 Stable baselines.
[&nbsp;<a href="https://github.com/hill-a/stable-baselines">http</a>&nbsp;]

</dd>

<dt>
[<a name="rl-zoo">Raffin, 2018</a>]
</dt>
<dd>
Raffin, A. (2018).
 Rl baselines zoo.
[&nbsp;<a href="https://github.com/araffin/rl-baselines-zoo">http</a>&nbsp;]

</dd>

<dt>
[<a name="journals/corr/abs-1907-10902">Akiba et&nbsp;al., 2019</a>]
</dt>
<dd>
Akiba, T., Sano, S., Yanase, T., Ohta, T., and Koyama, M. (2019).
 Optuna: A next-generation hyperparameter optimization framework.
 <em>CoRR</em>.
[&nbsp;<a href="http://arxiv.org/abs/1907.10902">http</a>&nbsp;]

</dd>
</dl>

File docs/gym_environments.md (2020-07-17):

**Table of content**:

[TOC]

* * *

# Introduction to reinforcement learning

**Reinforcement learning** (RL) consists in using machine learning techniques to
make decisions and control robots.
The domain studies how **an agent** can learn how to achieve goals in **an environment**.

At every step of the environment (each 50ms for our robot),
the agent sees **an observation** of this environment and send **an action** to take depending on **his policy**.

When learning, the environment also returns **a reward** at every step to indicate how bad the agent did act.
The sum of all these rewards when the episode ends is **the return** of this episode.

# OpenAI Gym environments

The **OpenAI Gym** library defines an interface to reinforcement learning
environments, making them easier to share and use.
Gym also provides a large collection of environments to benchmark different learning algorithms \[[Brockman et al., 2016](references.md#brockman2016openai)].

A Gym environment is a Python class implementing a set of methods:

```Python
import gym

class ExampleEnv(gym.Env):
    def __init__(self, param1=0.01, param2=False, param3=200):
        super().__init__()
        # Initialize the environment

    def reset(self):
        # Reset the environment
        return observation

    def step(self, action):
        # Do an action
        return observation, reward, done, {}

    def render(self, mode='human'):
        # Render the environment for human visualization or for recording

    def close(self):
        # Close environment
        
    def seed(self, seed=None):
        # Change the random number generator seed
```

## OpenAI Gym Reacher-v2

OpenAI Gym includes [an environment](https://github.com/openai/gym/blob/master/gym/envs/mujoco/reacher.py) of an robot arm in a 2D space which goal is to reach a target.
It uses [MuJoCo](http://www.mujoco.org/) which is a proprietary equivalent of BulletPhysics.

<iframe width="560" height="315" src="https://www.youtube-nocookie.com/embed/OtJ_6Nu8Ic0" frameborder="0" allow="accelerometer; autoplay; encrypted-media; gyroscope; picture-in-picture" allowfullscreen></iframe>

It is a great base to start with as one of our goals is to make one robot leg reach a target.

## Reinforcement learning tasks associated with kraby

The [gym_kraby](https://pypi.org/project/gym-kraby/) Python package includes
four OpenAI Gym environments:

-   `gym_kraby:HexapodBulletEnv-v0`: simulate full robot with BulletPhysics,

-   `gym_kraby:HexapodRealEnv-v0`: command the full real robot,

-   `gym_kraby:OneLegBulletEnv-v0`: simulate only one leg of the robot with
    BulletPhysics,

-   `gym_kraby:OneLegRealEnv-v0`: command only one leg of the robot.

You may install and test those environments by running in a Python environment:

```bash
pip install gym-kraby
python -m gym_kraby.demo --help
```

The package includes
[a demo script](https://github.com/erdnaxe/kraby/blob/master/gym_kraby/demo.py)
to test each environment.

Demo script in action

!!! Warning "Not tested"

    `gym_kraby:HexapodBulletEnv-v0` and `gym_kraby:HexapodRealEnv-v0` are quite similar to the "OneLeg" variant but they were not tested in learning.

## Using Kraby Gym environments

You may use these environments as any other OpenAI Gym environment.
You could also invoke the environment with `render=True` to show
PyBullet GUI.

```Python
import gym

env = gym.make('gym_kraby:HexapodBulletEnv-v0', render=True)
observation = env.reset()
score_return = 0
done = False

while not done:
    a = env.action_space.sample()  # take a random action
    observation, reward, done, _ = env.step(a)  # step
    score_return += reward

print("Environment episode is done, your total return was", score_return)
env.close()
```

As environments with only one leg cannot end prematuraly (and `done` will always returned true),
you may use a time limit wrapper:

```python
from gym.wrappers import TimeLimit

env_no_time_limit = gym.make('gym_kraby:HexapodBulletEnv-v0', render=True)
env = TimeLimit(env_no_time_limit, max_steps)
```

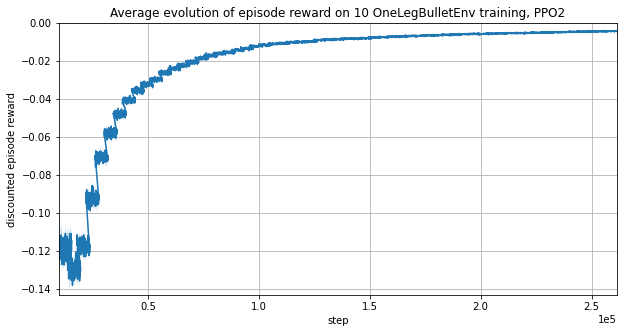
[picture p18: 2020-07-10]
docs/img/transfer_real_world_new_timestep.png

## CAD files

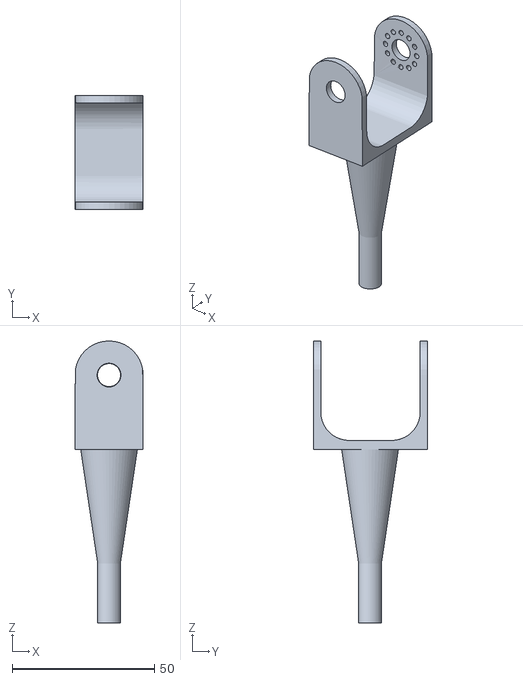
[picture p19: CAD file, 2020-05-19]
gym_kraby/data/meshes/foot.stl
24.0 x 40.0 x 99.3

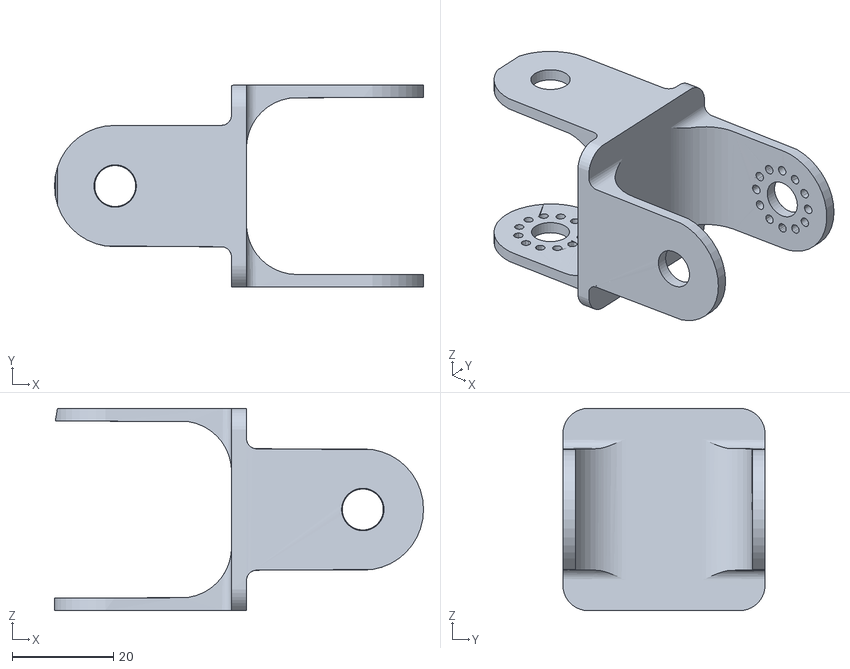
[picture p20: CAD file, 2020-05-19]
gym_kraby/data/meshes/joint.stl
73.0 x 40.0 x 40.0

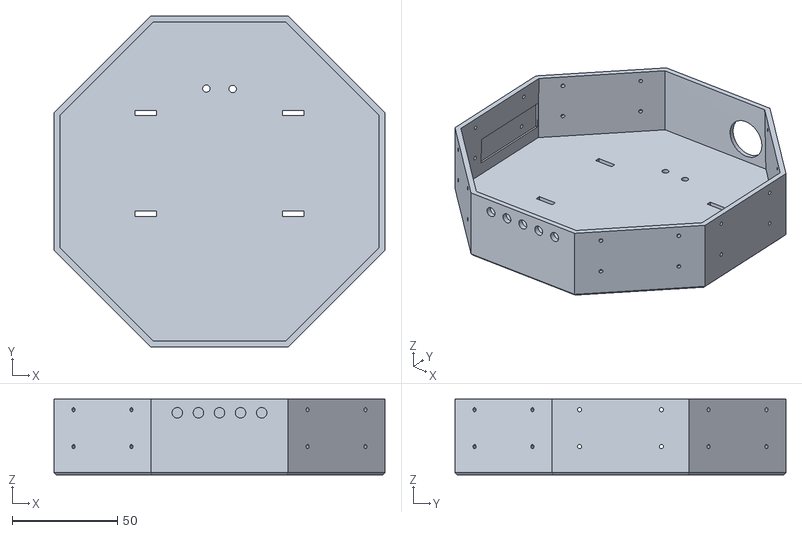
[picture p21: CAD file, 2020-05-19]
gym_kraby/data/meshes/box.stl
157.1 x 157.1 x 36.0

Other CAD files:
3d_parts/Blender/hexapod_2020_02_05.blend

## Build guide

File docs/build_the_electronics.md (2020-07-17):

**Table of content**:

[TOC]

* * *

# PCB

PCB were designed using Eagle 9, which demo version is sufficient.
PCB design files are available here :
<https://github.com/erdnaxe/kraby/tree/master/printed_circuit_boards>.

-   `printed_circuit_boards/nanopi_shield` is a shield that connects on NanoPi
    Neo4 expansion header and provides headers for UART, I2C and 5v power.
-   `printed_circuit_boards/power_board` is a power distribution board
    and connects all servomotors to one UART bus.

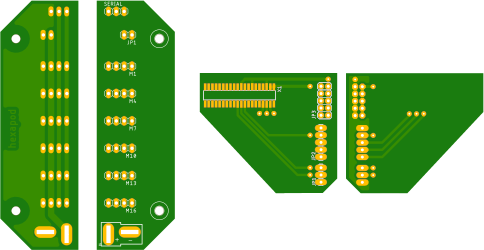
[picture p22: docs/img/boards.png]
Boards


!!! Warning "Only one serial port"

    These PCB connect all servomotors serial ports together.
    This may bottleneck your communication speed later, so if your board have more serial ports you may remix those files.

* * *

## Battery

### Battery requirements

Herkulex DRS-0101 requires a DC voltage from 7 to 12 V,
and draws approximately 500 mA (at 7 V) at maximum torque.
So the battery needs to be able to deliver **at least
9 A peak current** at a DC voltage **from 7 to 12 V**.

We choose 7 SubC NiMH cells at 3000 mAh each in series
but you may go with a Lithium battery
that will have a better capacity over mass, thus being more dangerous.
With the NiMH cells, we measured around 2 hours of autonomy using the robot.

!!! Danger "Battery protection and connection"

    For the battery, **you should use a fuse** and a switch in series
    and then connect onto the large battery connector of the power board.

### Powering the embedded computer

The embedded computer requires a 5 V DC voltage and can draw up to 3 A
peak current.
We choose _Texas Instrument LM2596_ Buck regulator as breakout boards exist and are simple to
use.

* * *

## How to wire it up

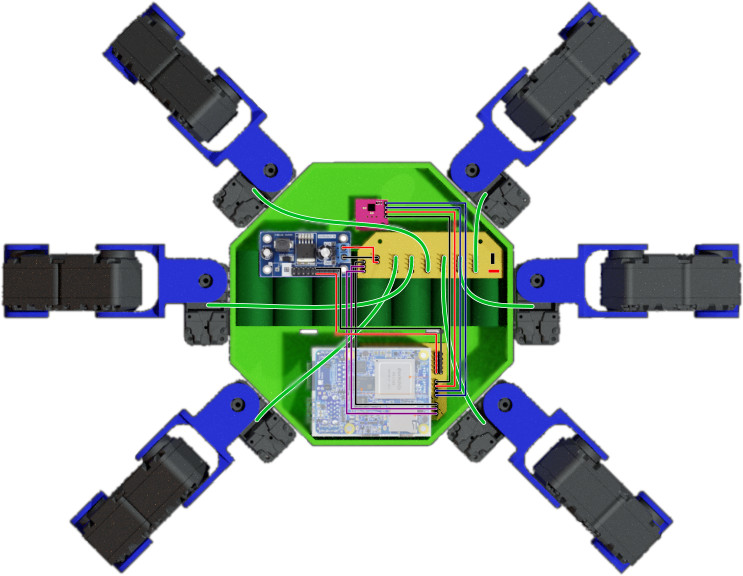
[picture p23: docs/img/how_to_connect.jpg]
Connection diagram


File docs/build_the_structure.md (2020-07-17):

**Table of content**:

[TOC]

* * *

# Build the structure

This section focuses on building the base structure of the robot.

Structure and electronics

* * *

## 3d-printed parts

This robot uses 3d-printed parts to be easily remixed.
Blender source files and STL are available
at <https://github.com/erdnaxe/kraby/tree/master/3d_parts>
or on [Thingiverse](https://www.thingiverse.com/thing:4135774).

This chassis also reuses the parts that come with Herkulex servomotors.

To build the robot, you will need to print:

-   6x `joint.stl`: top part of one leg,

-   6x `foot.stl`: bottom part of one leg,
    may be modified to adapt to different rubber endcap or touch sensor,

-   1x `box.stl`: main body of the robot,
    may be modified to adapt to different electronics.

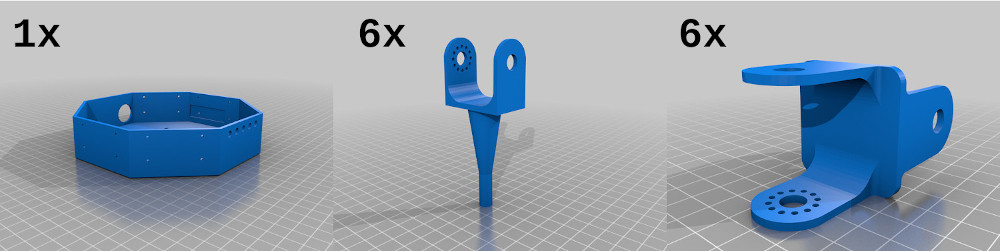
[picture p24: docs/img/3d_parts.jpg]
3D printed parts


If you are 3d-printing with a 0.2 layer height on a standard Cura profile,
it should take around 22h30 of printing, and one quarter of a one-kilogram
spool of plastic.

## Non-printed parts

-   18x [HerkuleX DRS-0101 servomotors](https://www.dfrobot.com/product-963.html)

-   7x SubC NiMH 3000mAh, mine are from [Conrad](https://www.conrad.fr/)

-   6x Rubber endcap 0.313" x 1.25", like [Lynxmotion REC-02](https://www.robotshop.com/eu/fr/capuchons-caoutchouc-lynxmotion-rec-02.html)

-   or 6x [Rubber endcap with foot switch](https://www.robotshop.com/eu/fr/pair-capteurs-contact-pied-lynxmotion.html)

-   optional 1x [NanoPi Neo4](http://wiki.friendlyarm.com/wiki/index.php/NanoPi_NEO4) or a serial interface

-   optional 1x [LM2596 - 5V 3A regulator board](https://www.robotshop.com/eu/fr/module-convertisseur-abaisseur-dc-dc-5v.html) (to power NanoPi for example)

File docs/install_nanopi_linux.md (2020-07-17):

**Table of content**:

[TOC]

* * *

# Compile NanoPi linux kernel with MPU9250 module

As of may 2020, only the official NanoPi kernel supports NanoPi Neo4 GPU and VPU.
The downside is this kernel does not include `inv-mpu6050` that supports the MPU9250,
so we are going to compile the kernel with this module.

`inv-mpu6050` is part of Linux Industrial I/O (IIO) subsystem driver
that provides an unified framework for sensors.
Learn more about IIO on [the official Linux Kernel documentation](https://www.kernel.org/doc/html/v4.14/driver-api/iio/index.html).

Install an ARM64 toolchain and download NanoPi kernel source code,

```bash
sudo apt install build-essential gcc-aarch64-linux-gnu gcc-arm-none-eabi
git clone https://github.com/friendlyarm/kernel-rockchip --depth 1 -b nanopi4-linux-v4.4.y
cd kernel-rockchip
```

Load NanoPi Linux configuration, `make ARCH=arm64 nanopi4_linux_defconfig`.

Add MPU9250 module, `make ARCH=arm64 menuconfig` then
`Device drivers > Industrial I/O support > Inertial measurement units > <*> Invensense MPU6050 devices`.

Add the MPU9250 to the board device-tree, edit `arch/arm64/boot/dts/rockchip/rk3399-nanopi4-common.dtsi`
and change:

```C
&i2c2 {
	status = "okay";

	mpu9250@68 {
		//compatible = "invensense,mpu9250";  // requires Linux 4.12
		compatible = "invensense,mpu6050";
		reg = <0x68>;
		interrupt-parent = <&gpio1>;
		interrupts = <0 IRQ_TYPE_LEVEL_HIGH>;
		/* Commented because requires Linux 4.12
		i2c-gate {
			#address-cells = <1>;
			#size-cells = <0>;
			ax8975@c {
				compatible = "ak,ak8975";
				reg = <0x0c>;
			};
		};*/
	};
};
```

Compile with `make ARCH=arm64 nanopi4-images`.
This will generate `kernel.img` and `resource.img` files.

!!! Note

    You may need to change `CONFIG_CROSS_COMPILE="aarch64-linux-gnu-"` in `.config`
    to point to the correct cross-compilation toolchain.

!!! Note

    You can directly update the running kernel without reflashing rootfs with
    `sudo dd if=kernel.img of=/dev/mmcblk1p5` and `sudo dd if=resource.img of=/dev/mmcblk1p4`.
    **Please use with caution, you may brick your device!**

## Install modified FriendlyCore

FriendlyCore uses an overlay filesystem, so removing software such as xorg after the flashing is useless.

Download FriendlyCore from <http://download.friendlyarm.com/NanoPiNEO4>.
At the time of wrtting this tutorial, it was `rk3399-eflasher-friendlycore-bionic-4.4-arm64-20200409.img`.

Dump image on a SD Card (at least 8GB), `dd if=rk3399-eflasher...img of=/dev/mmcblk0 status=progress`.

Remplace `friendlycore-arm64/kernel.img` and `friendlycore-arm64/resource.img` files on the SD card
with those generated in the previous section.

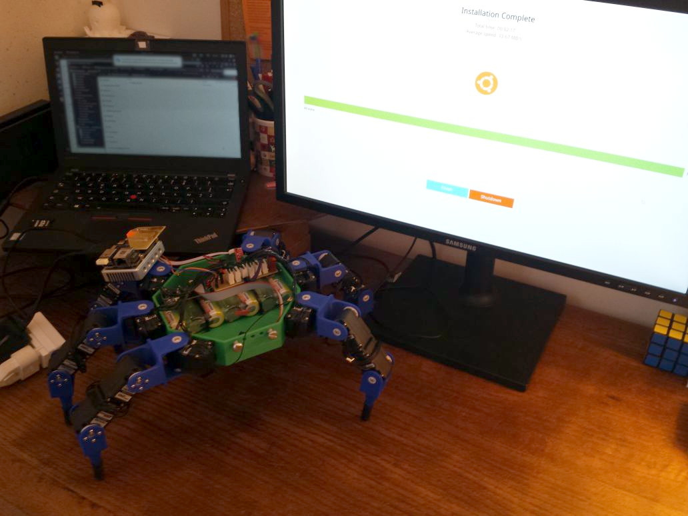
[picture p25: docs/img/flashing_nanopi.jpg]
Flashing process


Boot and install FriendlyCore with screen and keyboard attached, then reboot without SD card.
Run `npi-config` and change user password and enable SSH access.

Disable PWM Fan service, udisk, polkit, Bluetooth and ModemManager,
`sudo systemctl disable pwm-fan udisks2 polkit bluetooth ModemManager`.
Also block Bluetooth `sudo rfkill block 0`.

Edit `/etc/rc.local` to:

```bash
#!/bin/sh -e
exit 0
```

Add Hotspot WiFi network,

```bash
sudo nmcli dev wifi hotspot ifname wlan0 ssid Hexapod password "tfpopcorns"
sudo nmcli connection modify Hotspot autoconnect yes
sudo nmcli connection up Hotspot
```

Reboot and connect to WiFi "Hexapod" with password "tfpopcorns",
then `ssh pi@10.42.0.1`.

!!! Note

    You can plug wired Internet access
    and NetworkManager will automatically use and share this connection.

## Test the MPU9250

The iio kernel driver makes the MPU9250 available in
`/sys/bus/iio/devices/iio:device1` and `/dev/iio:device1`.

You can get the X-axis acceleration with

```bash
cat "/sys/bus/iio/devices/iio:device1/in_accel_x_raw"
```

Then you can try to stream a accelerometer axis,

```bash
echo 1 > "/sys/bus/iio/devices/iio:device1/scan_elements/in_accel_x_en"
echo 1 > "/sys/bus/iio/devices/iio:device1/buffer/enable"
hexdump -C /dev/iio\:device1
```

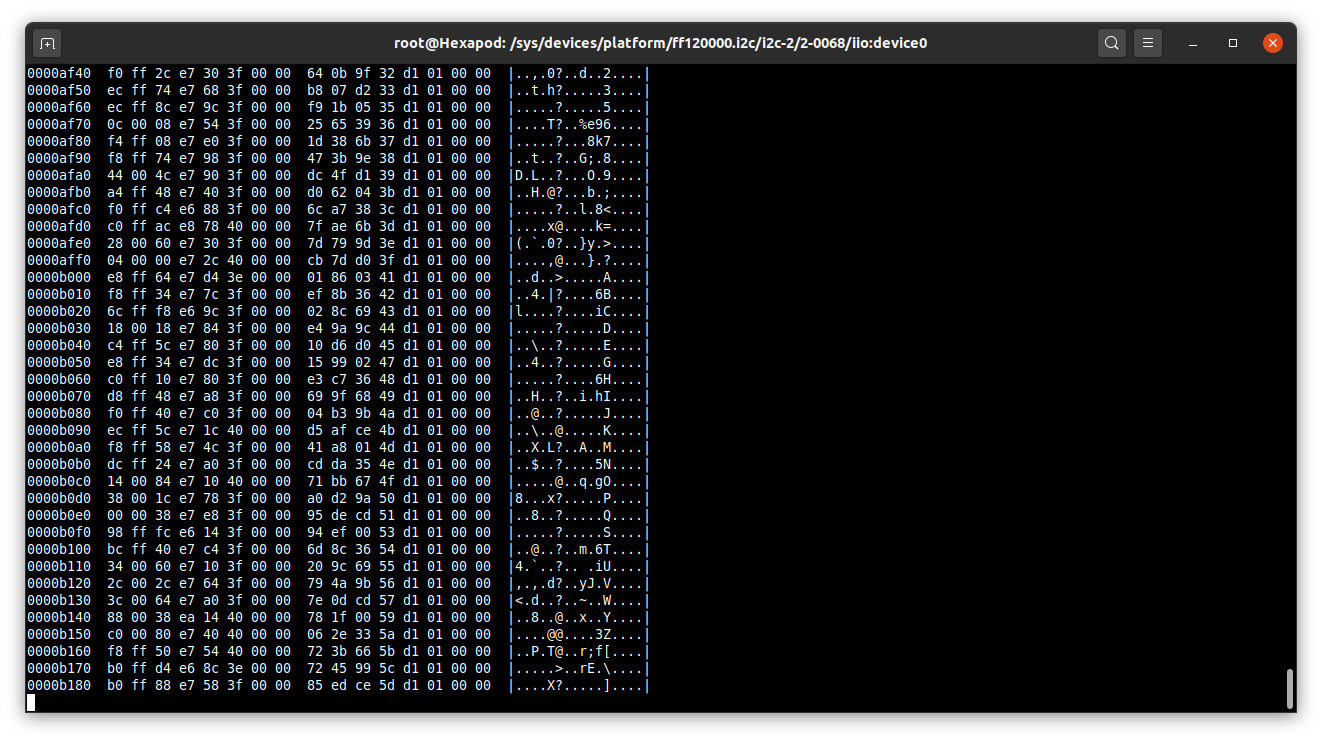
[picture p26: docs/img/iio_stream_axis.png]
X accelerometer streaming


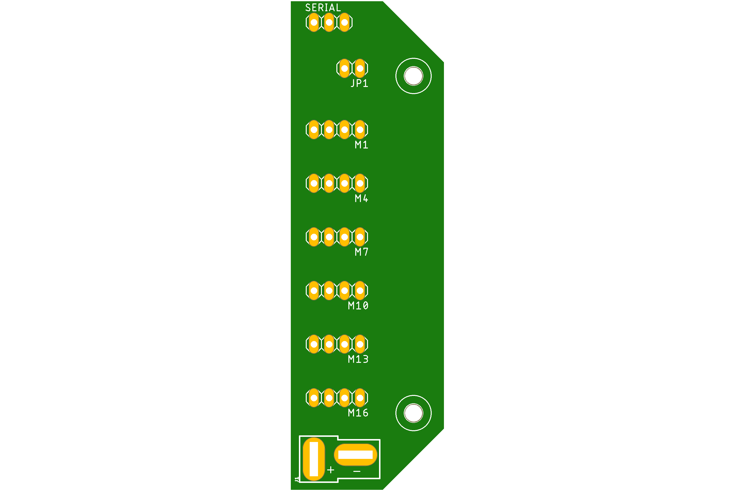
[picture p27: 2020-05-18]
printed_circuit_boards/power_board/power_board_top.png

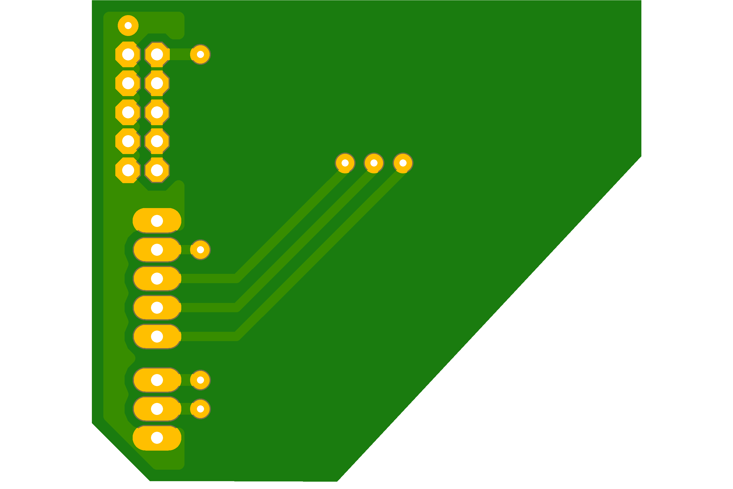
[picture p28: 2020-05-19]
printed_circuit_boards/nanopi_shield/nanopi_shield_top.png

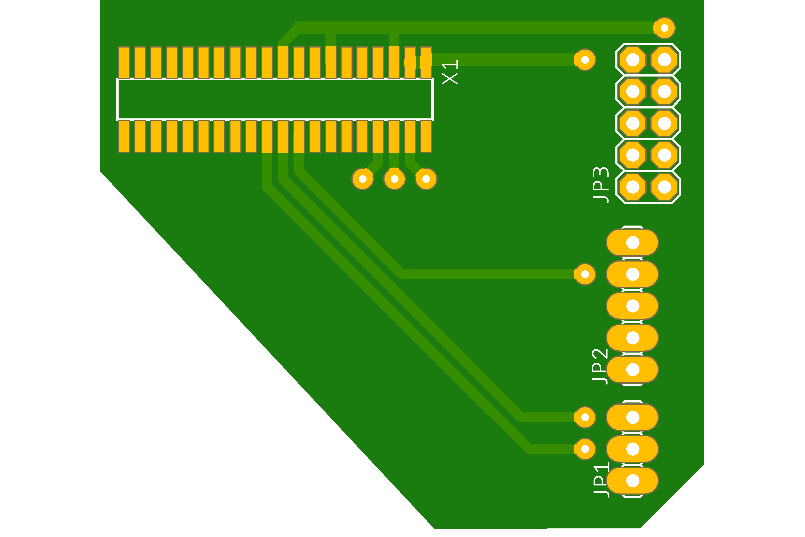
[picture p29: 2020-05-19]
printed_circuit_boards/nanopi_shield/nanopi_shield_bottom.png

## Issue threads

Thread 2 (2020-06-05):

Set endcap stiffness and damping

erdnaxe, 2020-06-05:
In `urdf_description/src/links/endcap.sdf.j2` the contact parameters are currently:
```xml
<contact>
  <stiffness value="30000"/> <!-- TODO -->
  <damping value="1000"/> <!-- TODO -->
</contact>
```

These correspond to a robot wheel. This may be changed by measuring these values.

erdnaxe, 2020-07-02:
Spinning friction (friction relative to reaction force normal) should be very low as there is little friction with a sphere geometry.

Lateral and rolling friction should be around 0.6 - 0.7, see values of <https://www.engineersedge.com/coeffients_of_friction.htm>.

erdnaxe, 2020-07-02:
The stiffness is the resistance offered by an elastic body to deformation, in N/m, 10 000 N/m should be good.

The damping is recommanded to 1000 for wheels in PyBullet Quickstart Guide. Need more research.

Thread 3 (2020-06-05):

Set servomotor joint damping, friction and limits

erdnaxe, 2020-06-05:
In `urdf_description/src/joints/joint_servomotor.sdf.j2`, there is currently:
```XML
    <dynamics damping="0" friction="0" /> <!-- TODO -->
    <!-- Herkulex : 361.4°/s i.e. 6.308rad/s, 12kg.cm i.e. 1.18Nm -->
    <limit effort="1.18" velocity="6.308" lower="-1.57" upper="1.57" /> <!-- TODO -->
```

We may need to add a damping and friction to this joint.
We also need to check that the converted effort and velocity is right.

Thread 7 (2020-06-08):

Servomotors 1, 4, 7, 10, 13, 16 blocked in simulation

erdnaxe, 2020-06-08:
After adding a torque limit, these motors can't move anymore.

erdnaxe, 2020-06-09:
They were colliding with the base of the robot.

Closed 2020-06-09.

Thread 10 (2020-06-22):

Set PyBullet timestep

erdnaxe, 2020-06-22:
For the moment, the simulation timestep is the same as the timestep of the environment. This may diverge the simulation is the timestep is too big.

erdnaxe, 2020-06-22:
The observation of 18 servomotors is limited to approximatively 30 ms period.

Quoting https://github.com/bulletphysics/bullet3/issues/1460#issuecomment-348303154, using a 30 ms simulation timestep might make it diverge. One solution is to do 8 simulation steps in 1 environment step.

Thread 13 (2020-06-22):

Test Herkulex observation getter

erdnaxe, 2020-06-22:
It seems that the method to receive observation does not properly work. Need more testing.

erdnaxe, 2020-06-22:
Servomotors id were not correctly assigned on robot. Fixed!

Closed 2020-06-22.

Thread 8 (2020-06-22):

Sometimes socket.recv does not receive the full message

erdnaxe, 2020-06-22:
```
Traceback (most recent call last):
  File "herkulex_socket.py", line 140, in <module>
    print(h.get_observations())
  File "herkulex_socket.py", line 112, in get_observations
    pos = ret[9] + ((ret[10] & 0x3) << 8)
IndexError: index out of range
```

This may be fixed by adding a loop on reception.

Closed 2020-06-22.

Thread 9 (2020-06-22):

Set min/max voltage of servomotors

erdnaxe, 2020-06-22:
The min voltage seems too high for the moment.

erdnaxe, 2020-06-24:
Useless as the default min/max voltage are already set to good values.
Default min voltage is 6.714 V -> 0.96 V per cell which correspond to the end of discharge.

Closed 2020-06-24.

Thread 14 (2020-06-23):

Implement "real" environments

erdnaxe, 2020-06-23:
`gym_kraby:HexapodRealEnv-v0` should command the full real robot and `gym_kraby:OneLegRealEnv-v0` should command only one leg of the robot.

To make these environments work, there is a need to

- [ ] Implement and test velocity command on Herkulex servomotors,
- [ ] Set all configuration parameters on Herkulex (such as torque limit),
- [ ] Check servomotor calibration values,
- [ ] Implement Magwick IMU fusion algorithm to get the orientation of the full robot.

erdnaxe, 2020-06-29:
Motor "move()" function sometimes does not send properly the message. Need more investigation.

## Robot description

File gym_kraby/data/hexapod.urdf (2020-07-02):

<?xml version="1.0" ?>

<robot name="hexapod">
  <link name="box">
    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
    <inertial>
      <origin xyz="0 0 0.203" rpy="0 0 0" />
      <mass value="0.667" />
      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
    </inertial>
  </link>

  
  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
  <joint name="fixed_box_servomotor_0" type="fixed">
    <origin xyz="0.06521292289492935 -0.06521292289492935 0.2041193" rpy="0 0 -0.78539" />
    <parent link="box" />
    <child link="servomotor_0" />
  </joint>
  <link name="servomotor_0">
    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
    <inertial>
      <origin xyz="0 0 0" rpy="0 0 0" />
      <mass value="0.047" />
      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
    </inertial>
  </link>
  <joint name="servomotor_0" type="revolute">
    <origin xyz="0 0.011 0" rpy="0 0 0" />
    <parent link="servomotor_0" />
    <child link="joint_0" />
    <axis xyz="0 0 1" />
    <dynamics damping="0" friction="0" /> 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
    <limit effort="1.18" velocity="6.308" lower="-0.46" upper="0.46" /> 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
  </joint>
  <link name="joint_0">
    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
    <inertial>
      <origin xyz="0.02432 0 0" rpy="0 0 0" />
      <mass value="0.011" />
      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
    </inertial>
  </link>
  <joint name="servomotor_1" type="revolute">
    <origin xyz="0.049 0 0" rpy="1.5707963267948966 -0.7853981633974483 0" />
    <parent link="joint_0" />
    <child link="servomotor_1" />
    <axis xyz="0 0 1" />
    <dynamics damping="0" friction="0" /> 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
    <limit effort="1.18" velocity="6.308" lower="-1.57" upper="1.57" /> 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
  </joint>
  <link name="servomotor_1">
    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
    <inertial>
      <origin xyz="0 -0.0107 0" rpy="0 0 0" />
      <mass value="0.047" />
      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
    </inertial>
  </link>
  <joint name="fixed_servomotor_1_servomotor_2" type="fixed">
    <origin xyz="0 -0.0495 0" rpy="0 0 3.141592653589793" />
    <parent link="servomotor_1" />
    <child link="servomotor_2" />
  </joint>
  <link name="servomotor_2">
    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
    <inertial>
      <origin xyz="0 0 0" rpy="0 0 0" />
      <mass value="0.047" />
      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
    </inertial>
  </link>
  <joint name="servomotor_2" type="revolute">
    <origin xyz="0 0.0107 0" rpy="0 0 -0.7853981633974483" />
    <parent link="servomotor_2" />
    <child link="foot_0" />
    <axis xyz="0 0 1" />
    <dynamics damping="0" friction="0" /> 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
    <limit effort="1.18" velocity="6.308" lower="-1.57" upper="1.57" /> 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
  </joint>
  <link name="foot_0">
    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
    <inertial>
      <origin xyz="0 0.031 0" rpy="1.5707963267948966 0 0" />
      <mass value="0.0105" />
      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
    </inertial>
  </link>
  <joint name="fixed_foot_0_endcap_0" type="fixed">
    <origin xyz="0 0.088 0" rpy="0 0 0" />
    <parent link="foot_0" />
    <child link="endcap_0" />
  </joint>
  <link name="endcap_0">
    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
    <inertial>
      <origin xyz="0 0 0" rpy="0 0 0" />
      <mass value="0.0005" />
      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
    </inertial>
    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
  </link>
  
  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
  <joint name="fixed_box_servomotor_3" type="fixed">
    <origin xyz="0.092225 0.0 0.2041193" rpy="0 0 0.0" />
    <parent link="box" />
    <child link="servomotor_3" />
  </joint>
  <link name="servomotor_3">
    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
    <inertial>
      <origin xyz="0 0 0" rpy="0 0 0" />
      <mass value="0.047" />
      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
    </inertial>
  </link>
  <joint name="servomotor_3" type="revolute">
    <origin xyz="0 0.011 0" rpy="0 0 0" />
    <parent link="servomotor_3" />
    <child link="joint_1" />
    <axis xyz="0 0 1" />
    <dynamics damping="0" friction="0" /> 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
    <limit effort="1.18" velocity="6.308" lower="-0.46" upper="0.46" /> 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
  </joint>
  <link name="joint_1">
    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
    <inertial>
      <origin xyz="0.02432 0 0" rpy="0 0 0" />
      <mass value="0.011" />
      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
    </inertial>
  </link>
  <joint name="servomotor_4" type="revolute">
    <origin xyz="0.049 0 0" rpy="1.5707963267948966 -0.7853981633974483 0" />
    <parent link="joint_1" />
    <child link="servomotor_4" />
    <axis xyz="0 0 1" />
    <dynamics damping="0" friction="0" /> 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
    <limit effort="1.18" velocity="6.308" lower="-1.57" upper="1.57" /> 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
  </joint>
  <link name="servomotor_4">
    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
    <inertial>
      <origin xyz="0 -0.0107 0" rpy="0 0 0" />
      <mass value="0.047" />
      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
    </inertial>
  </link>
  <joint name="fixed_servomotor_4_servomotor_5" type="fixed">
    <origin xyz="0 -0.0495 0" rpy="0 0 3.141592653589793" />
    <parent link="servomotor_4" />
    <child link="servomotor_5" />
  </joint>
  <link name="servomotor_5">
    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
    <inertial>
      <origin xyz="0 0 0" rpy="0 0 0" />
      <mass value="0.047" />
      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
    </inertial>
  </link>
  <joint name="servomotor_5" type="revolute">
    <origin xyz="0 0.0107 0" rpy="0 0 -0.7853981633974483" />
    <parent link="servomotor_5" />
    <child link="foot_1" />
    <axis xyz="0 0 1" />
    <dynamics damping="0" friction="0" /> 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
    <limit effort="1.18" velocity="6.308" lower="-1.57" upper="1.57" /> 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
  </joint>
  <link name="foot_1">
    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
    <inertial>
      <origin xyz="0 0.031 0" rpy="1.5707963267948966 0 0" />
      <mass value="0.0105" />
      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
    </inertial>
  </link>
  <joint name="fixed_foot_1_endcap_1" type="fixed">
    <origin xyz="0 0.088 0" rpy="0 0 0" />
    <parent link="foot_1" />
    <child link="endcap_1" />
  </joint>
  <link name="endcap_1">
    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
    <inertial>
      <origin xyz="0 0 0" rpy="0 0 0" />
      <mass value="0.0005" />
      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
    </inertial>
    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
  </link>
  
  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
  <joint name="fixed_box_servomotor_6" type="fixed">
    <origin xyz="0.06521292289492935 0.06521292289492935 0.2041193" rpy="0 0 0.78539" />
    <parent link="box" />
    <child link="servomotor_6" />
  </joint>
  <link name="servomotor_6">
    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
    <inertial>
      <origin xyz="0 0 0" rpy="0 0 0" />
      <mass value="0.047" />
      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
    </inertial>
  </link>
  <joint name="servomotor_6" type="revolute">
    <origin xyz="0 0.011 0" rpy="0 0 0" />
    <parent link="servomotor_6" />
    <child link="joint_2" />
    <axis xyz="0 0 1" />
    <dynamics damping="0" friction="0" /> 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
    <limit effort="1.18" velocity="6.308" lower="-0.46" upper="0.46" /> 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
  </joint>
  <link name="joint_2">
    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
    <inertial>
      <origin xyz="0.02432 0 0" rpy="0 0 0" />
      <mass value="0.011" />
      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
    </inertial>
  </link>
  <joint name="servomotor_7" type="revolute">
    <origin xyz="0.049 0 0" rpy="1.5707963267948966 -0.7853981633974483 0" />
    <parent link="joint_2" />
    <child link="servomotor_7" />
    <axis xyz="0 0 1" />
    <dynamics damping="0" friction="0" /> 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
    <limit effort="1.18" velocity="6.308" lower="-1.57" upper="1.57" /> 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
  </joint>
  <link name="servomotor_7">
    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
    <inertial>
      <origin xyz="0 -0.0107 0" rpy="0 0 0" />
      <mass value="0.047" />
      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
    </inertial>
  </link>
  <joint name="fixed_servomotor_7_servomotor_8" type="fixed">
    <origin xyz="0 -0.0495 0" rpy="0 0 3.141592653589793" />
    <parent link="servomotor_7" />
    <child link="servomotor_8" />
  </joint>
  <link name="servomotor_8">
    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
    <inertial>
      <origin xyz="0 0 0" rpy="0 0 0" />
      <mass value="0.047" />
      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
    </inertial>
  </link>
  <joint name="servomotor_8" type="revolute">
    <origin xyz="0 0.0107 0" rpy="0 0 -0.7853981633974483" />
    <parent link="servomotor_8" />
    <child link="foot_2" />
    <axis xyz="0 0 1" />
    <dynamics damping="0" friction="0" /> 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
    <limit effort="1.18" velocity="6.308" lower="-1.57" upper="1.57" /> 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
  </joint>
  <link name="foot_2">
    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
    <inertial>
      <origin xyz="0 0.031 0" rpy="1.5707963267948966 0 0" />
      <mass value="0.0105" />
      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
    </inertial>
  </link>
  <joint name="fixed_foot_2_endcap_2" type="fixed">
    <origin xyz="0 0.088 0" rpy="0 0 0" />
    <parent link="foot_2" />
    <child link="endcap_2" />
  </joint>
  <link name="endcap_2">
    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
    <inertial>
      <origin xyz="0 0 0" rpy="0 0 0" />
      <mass value="0.0005" />
      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
    </inertial>
    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
  </link>
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

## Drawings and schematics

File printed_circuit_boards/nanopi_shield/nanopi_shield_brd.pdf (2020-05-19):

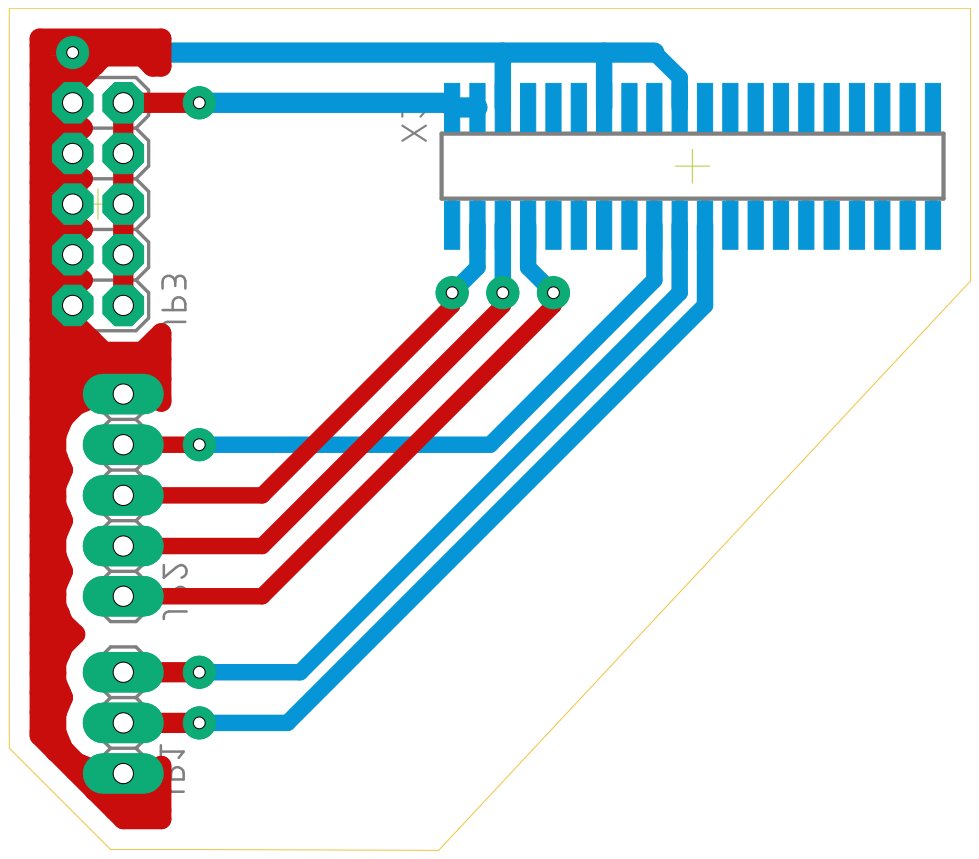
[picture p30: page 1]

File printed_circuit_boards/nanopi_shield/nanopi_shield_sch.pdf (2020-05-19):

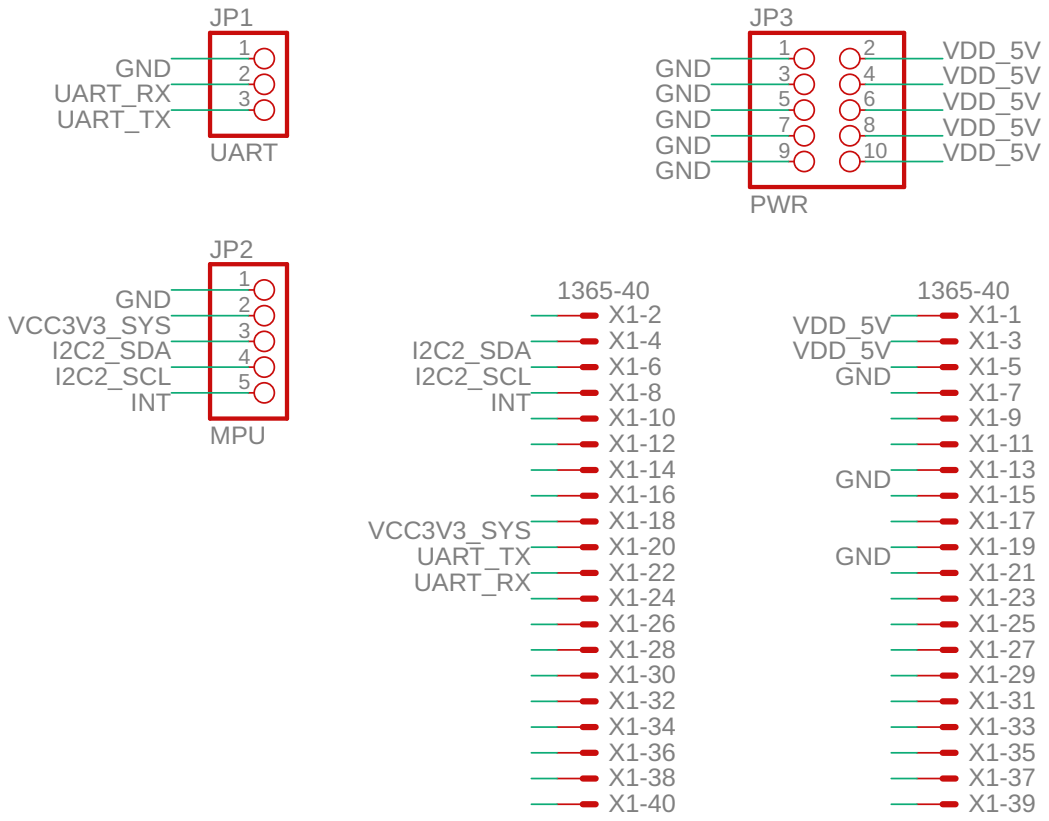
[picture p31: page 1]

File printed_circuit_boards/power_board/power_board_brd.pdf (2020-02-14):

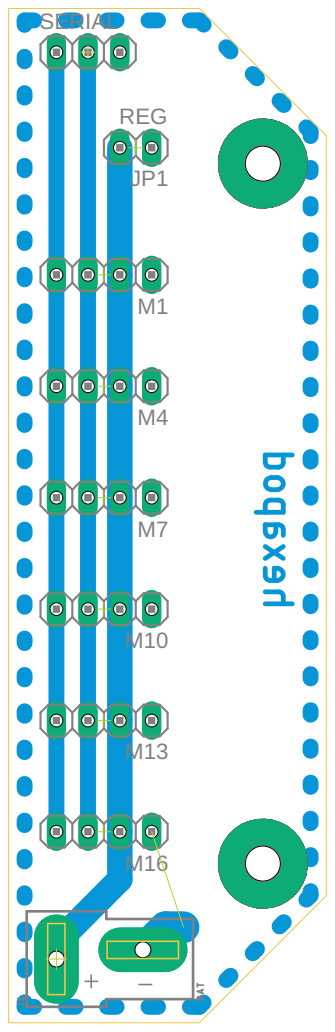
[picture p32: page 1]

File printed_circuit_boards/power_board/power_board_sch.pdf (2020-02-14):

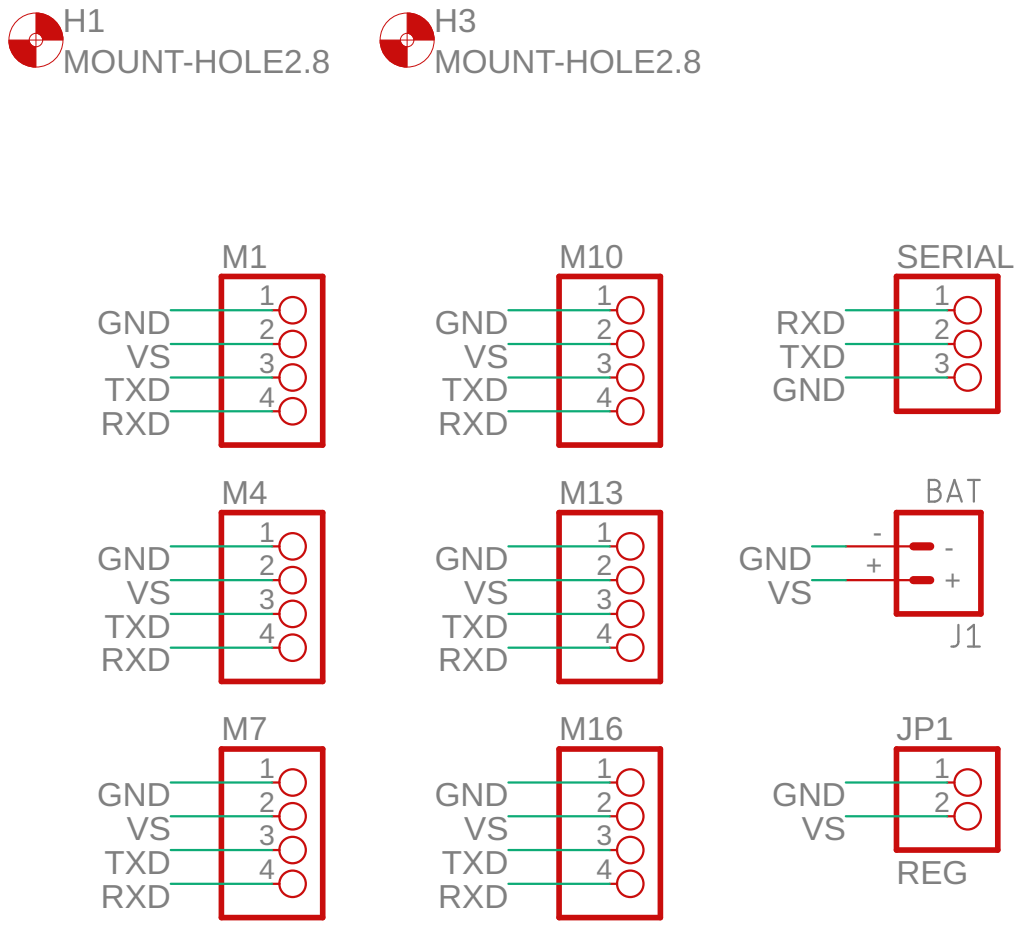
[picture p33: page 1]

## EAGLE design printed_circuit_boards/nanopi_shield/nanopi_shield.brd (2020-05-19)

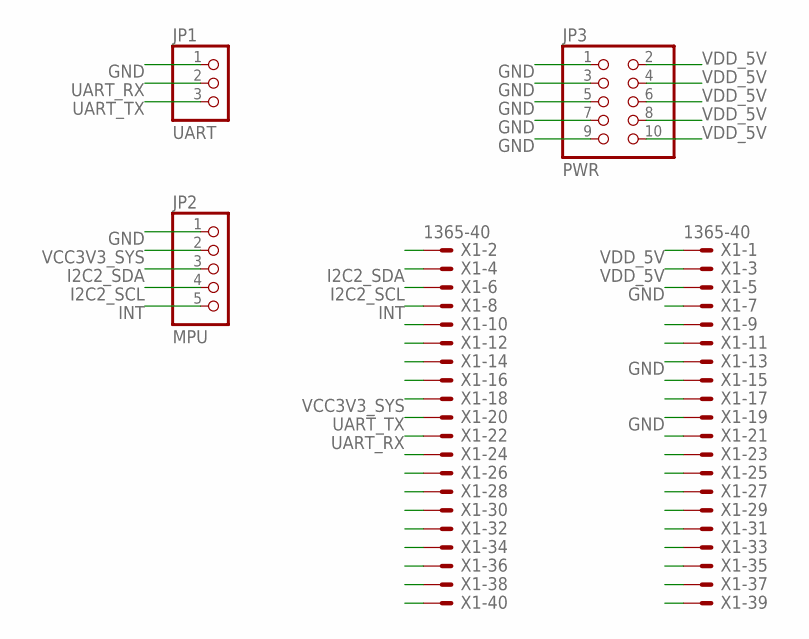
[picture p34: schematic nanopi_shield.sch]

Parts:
JP1: UART; 1X03
JP2: MPU; 1X05
JP3: PWR; 2X05
X1: 1365-40

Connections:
GND: JP1.1, JP2.1, JP3.1, JP3.3, JP3.5, JP3.7, JP3.9, X1.5, X1.13, X1.19
I2C2_SCL: JP2.4, X1.6
I2C2_SDA: JP2.3, X1.4
INT: JP2.5, X1.8
UART_RX: JP1.2, X1.22
UART_TX: JP1.3, X1.20
VCC3V3_SYS: JP2.2, X1.18
VDD_5V: JP3.2, JP3.4, JP3.6, JP3.8, JP3.10, X1.1, X1.3

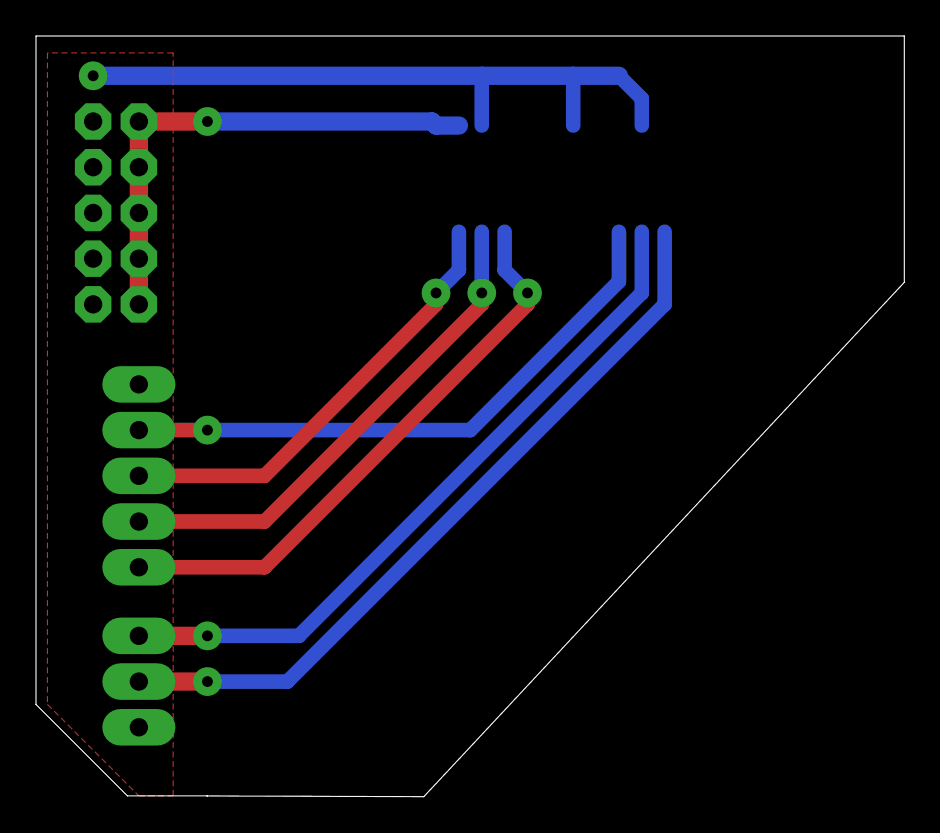
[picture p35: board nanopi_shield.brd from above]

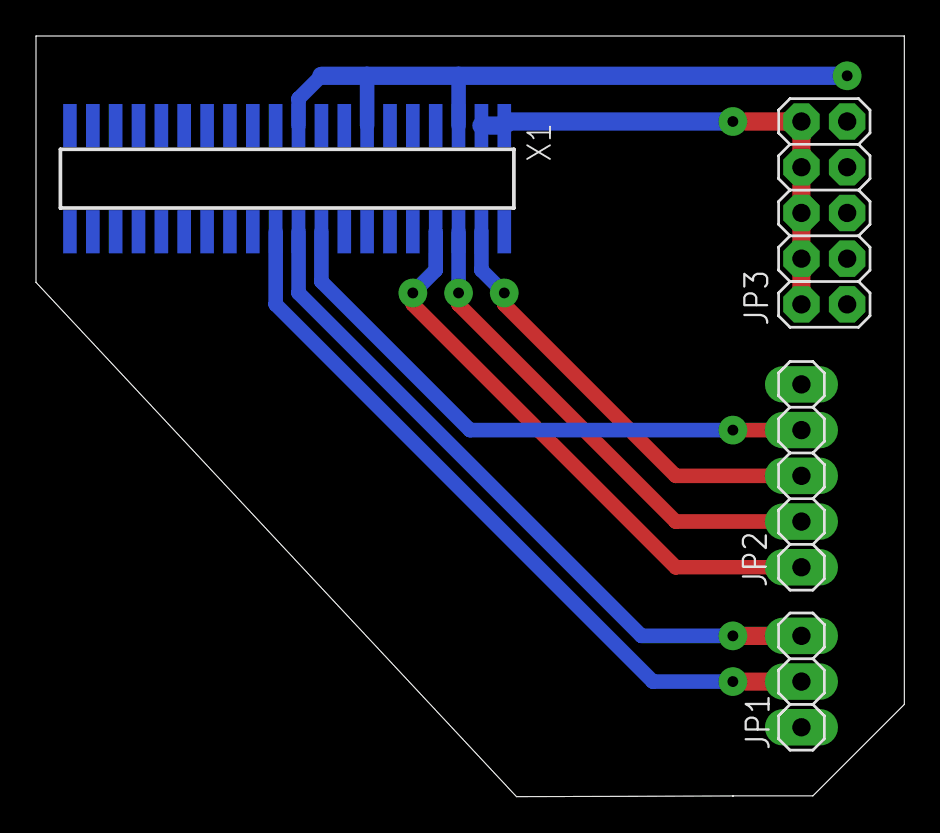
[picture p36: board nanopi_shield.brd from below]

Board: 2 copper layers, 48.2 x 42.3 mm, 4 parts (4 on the bottom side), 8 nets.

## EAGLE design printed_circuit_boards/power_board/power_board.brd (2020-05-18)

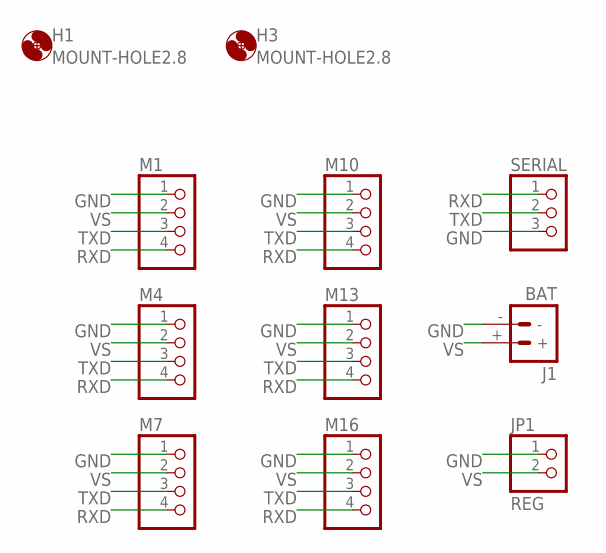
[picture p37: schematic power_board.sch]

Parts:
H1, H3: MOUNT-HOLE2.8; 2,8
J1: BAT; DEANS
JP1: REG; 1X02
M1, M4, M7, M10, M13, M16: PINHD-1X4; 1X04
SERIAL: PINHD-1X3; 1X03

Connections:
GND: J1.-, JP1.1, M1.1, M4.1, M7.1, M10.1, M13.1, M16.1, SERIAL.3
RXD: M1.4, M4.4, M7.4, M10.4, M13.4, M16.4, SERIAL.1
TXD: M1.3, M4.3, M7.3, M10.3, M13.3, M16.3, SERIAL.2
VS: J1.+, JP1.2, M1.2, M4.2, M7.2, M10.2, M13.2, M16.2

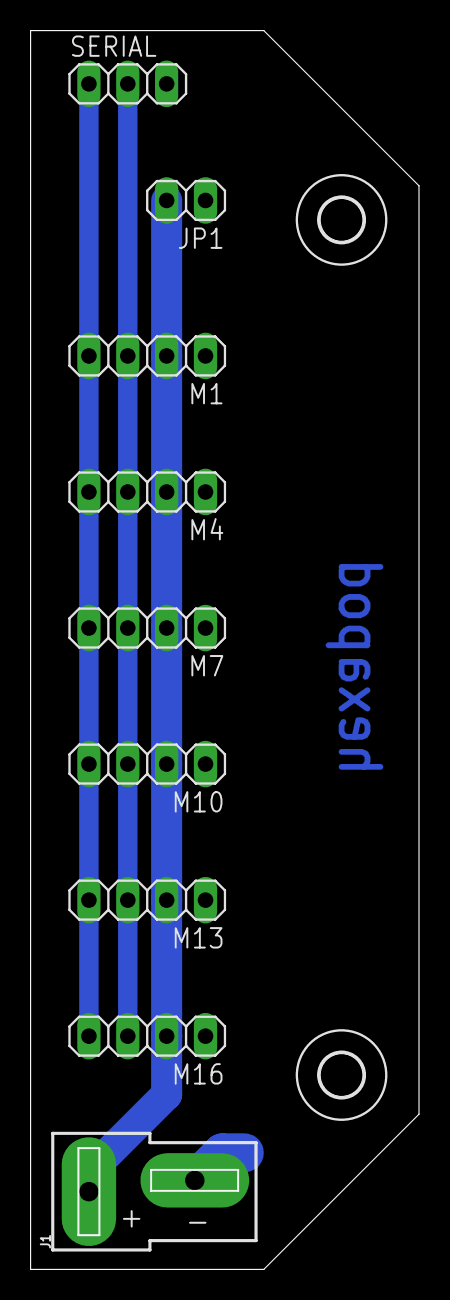
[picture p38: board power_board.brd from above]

Board: 2 copper layers, 25.4 x 81.0 mm, 11 parts (0 on the bottom side), 4 nets.

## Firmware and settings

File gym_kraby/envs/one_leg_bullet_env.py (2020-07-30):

import pybullet as p
import numpy as np
import gym
from gym import spaces
from pybullet_data import getDataPath
from time import sleep
try:
    import importlib.resources as pkg_resources
except ImportError:
    # backported to python<3.7
    import importlib_resources as pkg_resources


class OneLegBulletEnv(gym.Env):
    """One leg Hexapod environnement using PyBullet."""
    metadata = {
        "render.modes": ["human", "rgb_array"],
        "video.frames_per_second": 100,
    }

    def __init__(self, time_step=0.05, frameskip=12, delta=0.5, render=False):
        """
        Init environment.

        Args:
            time_step (float, optional): Environment time step in seconds. Defaults to 0.05.
            frameskip (int, optional): Sub steps for physic simulation. Defaults to 12.
            delta (float, optional): Size of the random in which the target will be randomly fixed. Defaults to 0.5.
            render (bool, optional): Open PyBullet GUI. Defaults to False.
        """
        super().__init__()

        # Init PyBullet in GUI or DIRECT mode
        self._render = render
        if self._render:
            # Try to connect to PyBullet render server
            cid = p.connect(p.SHARED_MEMORY)
            if (cid < 0):
                # Fail to connect, so launch a new server
                cid = p.connect(p.GUI)
        else:
            p.connect(p.DIRECT)

        # 3 actions (servomotors)
        self.n_actions = 3
        self.action_space = spaces.Box(low=-1, high=1,
                                       shape=(self.n_actions,),
                                       dtype="float32")

        # 3*(position,speed) + position target
        self.n_observation = 3*2+3
        self.observation_space = spaces.Box(low=-1, high=1,
                                            shape=(self.n_observation,),
                                            dtype="float32")
        self.observation = np.zeros(self.n_observation, dtype="float32")
        self.torques = np.zeros(self.n_actions)

        # Environment timestep and constants
        self.dt = time_step
        self.frameskip = frameskip
        self.servo_max_speed = 6.308  # rad/s
        self.servo_max_torque = 1.57  # N.m

        # Size of the box in which we pick the target
        self.delta = delta  # from 0 to 1

        # Seed random number generator
        self.seed()

        # Init world
        p.setTimeStep(self.dt / self.frameskip)  # between 0.001 and 0.01 s
        p.resetSimulation()
        p.setGravity(0, 0, -9.81)  # Newton's apple
        p.setAdditionalSearchPath(getDataPath())  # Add pybullet_data
        p.loadURDF("plane.urdf")  # Load a ground

        # Load robot
        flags = p.URDF_USE_SELF_COLLISION | p.URDF_USE_INERTIA_FROM_FILE
        # flags |= p.URDF_MERGE_FIXED_LINKS  # pybullet>2.89
        # flags |= p.URDF_IGNORE_VISUAL_SHAPES  # pybullet>2.89, see collisions
        with pkg_resources.path("gym_kraby", "data") as path:
            self.robot_id = p.loadURDF(str(path / 'one_leg.urdf'), flags=flags,
                                       useFixedBase=True)

        # Get all motorized joints id and name (which are revolute joints)
        self.joint_list = [j for j in range(p.getNumJoints(self.robot_id))
                           if p.getJointInfo(self.robot_id, j)[2] == p.JOINT_REVOLUTE]

    def reset(self):
        # Reset all joint using normal distribution
        for j in self.joint_list:
            p.resetJointState(self.robot_id, j,
                              np.random.uniform(low=-np.pi/4, high=np.pi/4))

        # Set random target and put it in observations
        self.target_position = np.array([
            np.random.uniform(0.219 - 0.069*self.delta,
                              0.219 + 0.069*self.delta),
            np.random.uniform(0.020 - 0.153*self.delta,
                              0.020 + 0.153*self.delta),
            np.random.uniform(0.128 - 0.072*self.delta,
                              0.128 + 0.072*self.delta),
        ])
        self.observation[-3:] = self.target_position

        # Show target as a crosshair
        p.removeAllUserDebugItems()
        p.addUserDebugLine(self.target_position - [0, 0, 0.01],
                           self.target_position + [0, 0, 0.01],
                           [0, 0, 0], 2)
        p.addUserDebugLine(self.target_position - [0, 0.01, 0],
                           self.target_position + [0, 0.01, 0],
                           [0, 0, 0], 2)

        # Return observation
        self._update_observation()
        return self.observation

    def step(self, action):
        # Update servomotors
        transformed_action = np.array(action) * self.servo_max_speed
        max_torques = [self.servo_max_torque] * self.n_actions
        p.setJointMotorControlArray(bodyIndex=self.robot_id,
                                    jointIndices=self.joint_list,
                                    controlMode=p.VELOCITY_CONTROL,
                                    targetVelocities=transformed_action,
                                    forces=max_torques)

        # Wait for environment step
        for _ in range(self.frameskip):  # step self.dt
            p.stepSimulation()
            if self._render:
                sleep(self.dt / self.frameskip)  # realtime

        # Return observation, reward and done
        self._update_observation()
        reward = self._get_reward()
        done = False
        return self.observation, reward, done, {}

    def render(self, mode='human'):
        """
        Render environment.

        PyBullet GUI can be disabled in favour of manual RGB rendering.

        Args:
            mode (str, optional): Render mode. Defaults to 'human'.

        Returns:
            np.ndarray: data array
        """

        # If not asking for a RGB array, return nothing
        if mode != "rgb_array":
            return np.array([])

        view_matrix = p.computeViewMatrixFromYawPitchRoll(
            cameraTargetPosition=[0, 0, 0.05],
            distance=0.6,
            yaw=30,
            pitch=-30,
            roll=0,
            upAxisIndex=2,
        )
        proj_matrix = p.computeProjectionMatrixFOV(
            fov=60,
            aspect=960./720,
            nearVal=0.1,
            farVal=100.0,
        )
        _, _, px, _, _ = p.getCameraImage(
            width=960,
            height=720,
            viewMatrix=view_matrix,
            projectionMatrix=proj_matrix,
            renderer=p.ER_TINY_RENDERER,
        )
        rgb_array = np.array(px)
        rgb_array = rgb_array[:, :, :3]
        return rgb_array

    def close(self):
        """Do nothing as PyBullet automatically closes."""
        pass

    @staticmethod
    def seed(seed=None):
        """Sets the seed for this env's random number generator."""
        np.random.seed(seed)
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

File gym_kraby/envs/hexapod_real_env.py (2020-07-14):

import numpy as np
import gym
from gym import spaces
from time import sleep, time
from ..utils.herkulex_socket import HerkulexSocket


class HexapodRealEnv(gym.Env):
    """Hexapod environnement for transfer to real robot."""

    def __init__(self, time_step=0.05, render=False):
        """
        Init environment.

        Args:
            time_step (float, optional): Environment time step in seconds. Defaults to 0.05.
            render (bool, optional): Unused, kept for compatibility.
        """
        super().__init__()

        # 18 actions (servomotors)
        self.n_actions = 18
        self.action_space = spaces.Box(low=-1, high=1,
                                       shape=(self.n_actions,),
                                       dtype="float32")

        # 18*(position,speed) + imu + position target
        self.n_observation = 18*2+6+3
        self.observation_space = spaces.Box(low=-1, high=1,
                                            shape=(self.n_observation,),
                                            dtype="float32")
        self.observation = np.zeros(self.n_observation, dtype="float32")

        # Environment timestep and constants
        self.dt = time_step
        self.servo_max_speed = 6.308  # rad/s
        self.servo_max_torque = 1.57  # N.m

        # Seed random number generator
        self.seed()

        # Servomotors socket
        self.servomotors = HerkulexSocket(
            max_velocity=self.servo_max_speed,
            max_torque=self.servo_max_torque,
        )

    def reset(self):
        # Reset servomotors
        self.servomotors.reset()
        sleep(1)

        # Set random target and put it in observations
        self.target_position = np.array([1., 0., 0.1])  # FIXME: make it random
        self.observation[-3:] = self.target_position

        # Return observation
        self._update_observation()
        return self.observation

    def step(self, action):
        initial_time = time()

        # Update servomotors
        transformed_action = np.array(action) * self.servo_max_speed
        transformed_action *= self.dt  # Training timestep
        self.servomotors.move(transformed_action)

        # Get observation (slow!)
        self._update_observation()
        while time() - initial_time < self.dt:
            pass # Wait for environment step

        # Return observation, reward and done
        reward = 0  # No reward in real mode
        done = False
        return self.observation, reward, done, {}

    def close(self):
        """Stop servomotors torque."""
        self.servomotors.disableTorque()

    @staticmethod
    def seed(seed=None):
        """Sets the seed for this env's random number generator."""
        np.random.seed(seed)

    def _update_observation(self):
        """
        Update the observation from servomotors sensors.

        Observation contains:
        * 3x servomotor {position, speed}
        * target (x, y, z)
        """
        # Each servomotor position and velocity
        obs, _ = self.servomotors.get_observations()
        self.observation[:2*18] = obs[:2*18]

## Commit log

2020-02-14 Power board
    [power_board.brd, power_board.sch]
2020-02-18 Add NanoPi Neo4 shield
    [nanopi_shield.brd, nanopi_shield.sch]
2020-02-18 Round corner
    [nanopi_shield.brd]
2020-02-19 Larger pads
    [nanopi_shield.brd]
2020-02-20 Larger via
    [nanopi_shield.brd]
2020-05-18 Easier to solder and fix I2C
    [nanopi_shield.brd, nanopi_shield.sch]
2020-05-18 Update power_board eagle version
    [power_board.brd]
2020-05-18 Add boards to readme
2020-05-19 MPU9250 interrupt pin
    [nanopi_shield.brd, nanopi_shield.sch]
2020-05-19 Add 3d parts
    [box.stl, foot.stl, hexapod_2020_02_05.blend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]
2020-05-19 3d printed parts illustration
2020-05-20 Use non staging MPU9250 driver
2020-05-22 ser2net for motors
2020-06-03 URDF description
    [hexapod.urdf]
2020-06-03 OpenAI Gym environnement
    [hexapod.urdf]
2020-06-04 URDF documentation
2020-06-04 URDF: Add core inertia
    [hexapod.urdf]
2020-06-04 Detect fallen robot
    [hexapod.urdf]
2020-06-08 Include URDF and STL in pip package
2020-06-08 Remove symlinks and add Pypi description
    [box.stl, foot.stl, hexapod.urdf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]
2020-06-08 One leg environment
    [one_leg.urdf]
2020-06-08 Update one leg env with normalization
2020-06-09 Make OneLeg base static
    [one_leg.urdf]
2020-06-09 Add seed and random initialization
    [hexapod.urdf, one_leg.urdf]
2020-06-09 Fix first servomotor collision
    [hexapod.urdf, one_leg.urdf]
2020-06-10 Reward for one leg
2020-06-11 pytorch-a2c-ppo-acktr-gail training for one leg
2020-06-19 Get data from servo in one command
2020-06-19 Docs: More background on servomotors
2020-06-20 Servomotors to 500000bps
2020-06-22 Local motor control test
2020-06-23 Make one leg observations more realistic
2020-06-24 Keep URDF loaded between two episodes
2020-06-24 Get motorized joints in init
2020-06-25 Add one leg env screenshot
2020-06-26 HexapodEnv: reset position and orientation
    [hexapod_bullet_env.py]
2020-06-26 RealEnv: Remove servomotors torque
2020-06-29 Fix initial position servomotor bug
2020-06-29 Herkulex velocity control
2020-06-29 Add motor demo video
2020-06-29 Fix #4: hexapod is no longer sliding
    [hexapod.urdf, one_leg.urdf]
2020-06-29 Growing box for one leg objective
2020-06-30 Clip velocities
2020-07-01 Position motor control
2020-07-01 Fun script to test motors
2020-07-02 Update contact coefficients, see #2
    [hexapod.urdf, one_leg.urdf]
2020-07-02 Clean up one leg env
2020-07-03 Reorder one leg training doc
2020-07-06 Training without torque in obs
2020-07-07 Better hyperparameters and no more fingertip position
2020-07-08 Implement frameskip in envs
2020-07-08 Fix doctring ponctuation (PEP257)
    [hexapod_bullet_env.py, hexapod_real_env.py, one_leg_bullet_env.py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]
2020-07-14 RealEnv: Wait only if too fast
    [one_leg_real_env.py]
2020-07-17 Switch to MIT license
2020-07-30 Some experiments with one leg
2020-08-13 Rewrite training one leg doc
2020-08-14 End of doc one leg

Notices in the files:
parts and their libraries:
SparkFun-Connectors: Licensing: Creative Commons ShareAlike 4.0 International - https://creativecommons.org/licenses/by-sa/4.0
